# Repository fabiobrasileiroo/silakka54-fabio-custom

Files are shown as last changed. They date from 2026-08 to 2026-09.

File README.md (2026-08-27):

# Silakka54 — Pacote de Impressão "Fabio custom" (v3.0 "FB + Tux + linux + Kit 2-em-1")

Pasta autocontida com todo o histórico do projeto: dos arquivos originais (zip) até a
**versão final personalizada**, pronta para mandar imprimir.

> 🌐 **Site com visualizador 3D interativo (GitHub Pages):**
> **https://fabiobrasileiro.me/silakka54-fabio-custom/**
> (three.js via CDN + STLs servidos pelo jsDelivr; inclui guia de ergonomia)

## Referências visuais

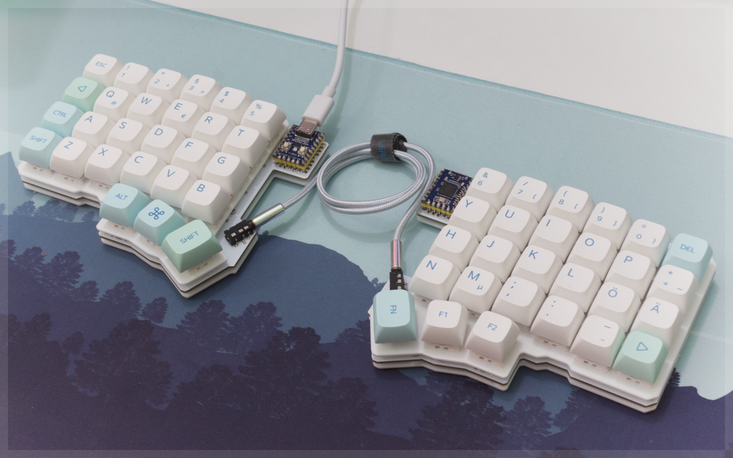
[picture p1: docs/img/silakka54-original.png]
Silakka54 original — teclado montado


Fotos de referência (de terceiros, para demonstrar como o teclado fica montado):

- **Original do autor** — [squalius-cephalus.github.io/silakka54](https://squalius-cephalus.github.io/silakka54/) (Patrick Faulkner)
- **Exemplo real montado** — [Reddit r/ErgoMechKeyboards](https://www.reddit.com/r/ErgoMechKeyboards/comments/1nzly97/my_first_split_silakka54_from_aliexp_w_3d_printed/) (`docs/img/silakka54-assembled.jpg`)

📸 A foto do meu teclado montado será adicionada quando chegar.

## Estrutura

```
silakka54-pacote-impressao/
├── README.md                    ← este arquivo (visão geral)
├── CHANGELOG.md                 ← histórico detalhado de todas as modificações
├── INSTRUCOES_IMPRESSAO.md      ← guia para a pessoa que vai imprimir (LEIA ANTES)
├── CHECKSUMS.sha256             ← hashes de integridade de todos os arquivos
├── pyproject.toml               ← dependências das ferramentas (uv / Python)
├── 00-original/
│   ├── case-keyboard/           ← arquivos ORIGINAIS do zip (intactos) + PDF de montagem
│   ├── carry-case/              ← arquivos ORIGINAIS do carry case (intactos) + PDF
│   └── tent-tilt-kit/           ← arquivos ORIGINAIS do kit ergonômico tent/tilt
├── 01-final/                    ← ⭐ VERSÃO FINAL PARA IMPRIMIR ⭐
│   ├── LH/                      ← baseplate "Foi o JavaScript..." (corrigida) + cover "FB + Tux + linux"
│   ├── RH/                      ← baseplate "Foi o Java..." (corrigida) + cover "FB + Tux + linux"
│   ├── comum/                   ← top frame (imprimir 1 direto + 1 espelhado)
│   ├── carry-tent-2em1/         ← Kit 2-em-1 Carry Case (67mm/standard) + plataforma Tent/Tilt
│   └── previews/                ← pré-visualizações das peças e plaquetas
├── ferramentas/                 ← scripts de regeneração (engrave_baseplate.py / engrave_cover.py)
└── 02-superseded/               ← versões anteriores arquivadas
```

## O que foi feito (resumo de 1 linha)

A case original foi customizada na **v3.0**: covers com plaqueta **"FB + silhueta Tux (Linux)"** e texto lateral **"linux"**, baseplates com **"Foi o JavaScript que me deu"** (LH) / **"Foi o Java que me deu"** (RH) gravadas na face inferior com **orientação 100% legível por baixo (sem espelhamento)**, e o **Kit 2-em-1 Carry Case + Tent** reunido e pronto para uso.

Detalhes completos (medidas, fontes, eixos de espelhamento, verificações): **CHANGELOG.md**.

## Para imprimir

1. Leia **INSTRUCOES_IMPRESSAO.md** (lista de peças, quantidades, orientação).
2. Use os arquivos de **`01-final/`** (incluindo `01-final/carry-tent-2em1/` para o kit 2-em-1).
3. Regra de ouro: **arquivos `*RH*` já vêm espelhados — nunca espelhar de novo**; o único
   espelhamento a fazer é **1 cópia do top frame** (lado direito).

## Para modificar depois

- Texto/fonte/tamanho/posição das gravações → dá para **regenerar por script**:
  `cd ferramentas && poetry run python engrave_cover.py` (dependências gerenciadas pelo
  Poetry via `pyproject.toml`; instale com `poetry install` na raiz).
- Carry case → pode ser adaptado depois (pendente, proposital).
- Tenting platform (ergonomia 10–15°) → **incluído**: `00-original/tent-tilt-kit/`
  (kit Tent & Tilt Ergonômico de Douglas Serrão, original sem modificação).

## Licenças / créditos

- **Silakka54** — Patrick Faulkner (GPL v2.0; remix permitido com atribuição).
- **Case "less screws" / screwless + carry case** — remix de Douglas Serrão.
- Fontes: Audiowide (OFL 1.1), JetBrains Mono (OFL 1.1), DejaVu Sans (tux.png —
  Wikimedia Commons, silhueta oficial do Linux).

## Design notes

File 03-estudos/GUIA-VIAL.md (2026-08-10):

# Guia de uso — Vial no Silakka54 (RP2040)

Como configurar o teclado **sem instalar nada**: via **Vial Web** (vial.rocks), com backup
e camadas. Baseado na documentação oficial do Vial e no firmware oficial do Silakka54
(repo Squalius-cephalus, v1.4 = Vial 0.7.5).

---

## 0. O que é o Silakka54 (seu teclado)

- Board **wired** com 2× RP2040 Zero (1 por metade), 54 teclas split colunar
  (6×4 + 3 thumb por metade), hotswap MX.
- Firmware oficial com **Vial embutido** = remapear ao vivo, sem recompilar nada.
- ⚠️ Existem clones **wireless** ("Silakka54 sem fio") que usam nice!nano/ZMK e **NÃO
  funcionam com Vial**. Se o seu é o *wired* com RP2040 (como o da AliExpress "QMK VIAL
  Programável RP2040 Zero"), está correto.

## 1. Do que você precisa

| Ferramenta | Onde | Quando |
|---|---|---|
| **Vial Web** (recomendado) | https://vial.rocks/ | Remapear, camadas, macros, backup |
| **Vial Desktop** (alternativa) | https://get.vial.today/download/ | Funciona offline; necessário no Linux p/ udev |
| **Manual oficial do Vial** (EN) | https://get.vial.today/manual/ | Dúvidas de funcionalidade |
| **Firmware oficial (UF2)** | https://github.com/Squalius-cephalus/silakka54/releases | Só se o teclado não for detectado |
| **Site do projeto** | https://squalius-cephalus.github.io/silakka54/ | Firmware + troubleshooting |

> 🌐 **Vial Web funciona melhor no Chrome/Edge** (usa WebHID). Firefox não suporta WebHID.

---

## 2. Primeira conexão (5 min)

1. **TRRS obrigatório**: conecte as 2 metades com cabo **TRRS (4 pinos)** — cabo TRS (3
   pinos) NÃO funciona. Connector de pré-montados costuma ser bem apertado: encaixe até o
   fim.
2. Conecte a **metade master** (a que tem USB) ao PC com cabo USB-C. Em teclados pré-montados
   da AliExpress, quase sempre é o lado que tem a porta + a ordem de flash define (LEFT/RIGHT).
3. Abra **https://vial.rocks/** → clique em **Connect** (ícone de teclado) → selecione o
   dispositivo "Silakka54".
4. **Teste todas as teclas**: aba **Key tester** (ou digite num editor) — confira se cada
   tecla responde. Se metade não responder, veja Troubleshooting (seção 7).
5. Se o layout mostrado no Vial não bater com o teclado físico, **atualize o firmware**
   (seção 6).

> 💡 If o precia: o firmware de fábrica dos pré-montados frequentemente tem **layout
> mínimo de 1 camada e keycaps trocadas** (ex.: pgup = Enter, del = Backspace). Não é
> defeito — é só remapear (seção 3).

---

## 3. Remapear teclas (o essencial)

1. No Vial Web, aba **Layout** (teclado desenhado em cima, paleta de teclas embaixo).
2. Clique na tecla física que quer mudar (ela fica destacada).
3. Clique na função nova na paleta (ou use a busca "Any key" para keycodes crus, ex. `KC_NO`).
4. **Já era** — a mudança é salva **na flash do teclado** imediatamente. Sobrevive a
   desligar, trocar de PC, tudo. Não precisa de "salvar" nem reflash.

Conceitos rápidos:
- **▽ (Transparent)**: "herda" da camada de baixo — usado para montar camadas.
- **MO(x)**: segura e ativa a camada x (mais usado).
- **LT(x, tecla)**: tap = tecla normal, hold = camada x (ex.: LT(1, Space)).
- **TG(x)**: liga/desliga a camada x (toggle).
- **OSL(x)**: camada x por UM toque (one-shot).
- **Layer Lock**: o firmware tem `LAYER_LOCK_ENABLE` — use tecla **QK_LLCK** para travar a
  camada atual (Caps Lock de camada).

## 4. Camadas — você tem 8!

O build Vial oficial do Silakka54 vem com **8 camadas** (`DYNAMIC_KEYMAP_LAYER_COUNT 8`),
muito mais que as 4 padrão do Vial. Sugestão de organiização:

| Camada | Função |
|---|---|
| 0 | Base (letras/números) |
| 1 | Símbolos e F-keys (via MO nas thumbs) |
| 2 | Navegação (setas, Home/End/PgUp/PgDn) |
| 3 | Mouse/Media (opcional) |

Dica de split de 54: coloque **Space / Enter / camadas nos thumb clusters** (3 thumbs por
metade) e tire a carga dos mindinhos. Exemplo de base:
- Esquerda: **Space** (thumb maior), **MO(1)** (thumb 2), **Backspace** (thumb 3)
- Direita: **Enter** (thumb maior), **MO(2)** (thumb 2), **Del** (thumb 3)

## 5. Macros, combos e tap-hold

- **Macros** (aba Macros): até 16 slots (M0–M15). Grave com **Record** ou monte ações na
  mão (tap/hold/delay). Atribua `M0` etc. a qualquer tecla. Ex.: M0 = "silakka54" +
  Enter; M1 = Ctrl+Shift+Esc.
- **Combos** (aba Combos): até 2–4 teclas juntas disparam UMA ação (ex.: **F+J = Enter**,
  **Esc = A+S**). Não ocupa slot de tecla — ótimo em split pequeno.
- **Tap-hold / home-row mods** (aba QMK Settings): ajuste `Tapping Term` (ex.: 180–220 ms).
  Se uma tecla "segurar vira shift" está disparando shift sem querer, aumente o termo.

## 6. Atualizar firmware (só se precisar)

**Quando**: teclado não aparece no Vial, ou quer a versão mais recente (v1.4, Vial 0.7.5,
com suporte a LEDs de camada).

1. **Backup primeiro**: Vial → `File` → `Save current layout` → salve seu `.vil` (o reflash
   **apaga o layout**). Desde o Vial 0.7.5 o **web app** (vial.rocks) também salva/abre
   `.vil` — Chrome/Edge: menu do layout (ou Ctrl+S / Ctrl+O). O firmware v1.4 do Silakka54
   já vem com Vial 0.7.5.
2. Baixe o **UF2** em https://github.com/Squalius-cephalus/silakka54/releases:
   - `silakka54_vial_LEFT.uf2` → metade esquerda
   - `silakka54_vial_RIGHT.uf2` → metade direita
   - (existe versão `NO_USBDETECT` se a normal não funcionar)
3. **Mode bootloader** de 2 jeitos:
   - Sem firmware: segure **BOOT** no RP2040 Zero e conecte ao USB.
   - Com firmware: **duplo clique no botão reset** → aparece drive USB.
4. **Arraste o `.uf2`** para o drive (drag-and-drop). A placa reinicia sozinha.
5. Repita na outra metade com o arquivo da outra metade (ou mesmo LEFT nas duas para
   forçar USB na esquerda; RIGHT nas duas para USB na direita).
6. Reabra o Vial e **carregue o `.vil`** de volta (`File` → `Load saved layout`).

> Se o Vial Web não for detectar o teclado no Linux com o app desktop: siga
> https://get.vial.today/manual/linux-udev.html (regra udev fornecida).

## 7. Troubleshooting rápido

| Sintoma | Causa provável | Solução |
|---|---|---|
| Metade direita morta | Cabo TRRS solto/apertado, ou **TRS** (3 pinos) | Encaixe com força; troque por TRRS |
| Teclas "trocadas" (pgup=Enter etc.) | Keycaps de fábrica mal rotuladas | Remapeie no Vial (ou troque keycaps) |
| Teclado some ao reiniciar o PC | Firmware antigo (issue de boot) | Atualizar para v1.4 |
| Vial não conecta | Versão wireless (ZMK) ou firmware faltando | Verificar modelo; reflash UF2 |
| Texto/tecla errada ao digitar | Layout do SO ≠ layout do teclado | Ajuste no sistema (ABNT2/US Intl) e remapeie |
| Algumas teclas sem resposta | Pino de switch torto / socket | Tira e recoloca o switch (pinos retos) |
| Vial Web mostra teclado "bloqueado" | Proteção de segurança do Vial Web | Digite o unlock combo **Esc + 1** (tecla de esc + tecla 1 juntas) para desbloquear |

**Referências**: manual oficial Vial (https://get.vial.today/manual/) · firmware oficial
Silakka54 (https://squalius-cephalus.github.io/silakka54/firmware.html) · repo
(https://github.com/Squalius-cephalus/silakka54).

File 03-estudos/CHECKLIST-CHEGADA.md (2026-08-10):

# Checklist "Dia 1" — quando o Silakka54 chegar

Ordem cronológica para montar, testar e configurar. Imprima ou abra no celular.

---

## □ Antes de abrir (planejar)

- [ ] Reserve mesa limpa + luz; tenha em mãos:
  - cabo **USB-C** (pré-montados da AliExpress às vezes **NÃO incluem**)
  - cabo **TRRS** (4 pinos) — se não veio, compre; TRS não funciona
  - chave de fenda pequena (não deve precisar para hotswap)
- [ ] Abra https://vial.rocks/ no **Chrome/Edge** para testar (guardar no favoritos)
- [ ] Tenha em mente: os dois zips/case impressa em `silakka54-pacote-impressao/`

## □ Unboxing físico

- [ ] Confira itens: 2 metades, switches (se kit), keycaps, cabos
- [ ] Se for kit (montar): coloque os **switches** nos sockets hotswap — pinos retos,
      força para baixo até o "click". Não force torto!
- [ ] Coloque as **keycaps** (⚠️ as de fábrica podem vir trocadas: pgup=Enter, del=Backspace —
      normal, remapear depois)
- [ ] Se usar a case impressa: monte baseplate + top frame → encaixe o PCB → covers chevron

## □ Conexão e primeiro teste

- [ ] Conecte as metades com o **TRRS** (ate o fim — conector de pré-montado é apertado)
- [ ] USB-C na **metade master** (a que tem o conector) → PC
- [ ] Abra https://vial.rocks/ → **Connect** → deve aparecer "Silakka54"
- [ ] **Key tester**: teste TODAS as 54 teclas (com o software "Key tester" ou num editor
      de texto) — as duas metades respondem?
- [ ] NÃO apareceu? → atualizar firmware (ver GUIA-VIAL.md seção 6: BOOT + uf2)

## □ Configuração no Vial (30–60 min)

- [ ] Mapear base: corrigir keycaps trocadas; colocar **camadas nas thumbs** (ex.:
      MO(1) thumb esquerda, MO(2) thumb direita, Space/Enter nas thumbs grandes)
- [ ] Camada 1: **setas + Home/End/PgUp/PgDn** + símbolos que usa muito
- [ ] Camada 2: **F1–F12** + atalhos (Ctrl+Shift+Esc etc.) — você tem **8 camadas**!
- [ ] (Opcional) Combos: Esc = A+S, Enter = F+J
- [ ] Ajustar **Tapping Term** (QMK Settings) se usar home-row mods
- [ ] **Backup**: File → Save current layout → `silakka54-layout-dia1.vil`
      (guarde uma cópia dentro de `silakka54-pacote-impressao/03-estudos/backups/`)

## □ Setup ergonômico na mesa (ver REPORT-ERGONOMIA.md)

- [ ] Metades na **largura dos ombros**, anguladas para dentro (punhos retos)
- [ ] Teclado **abaixo da altura do cotovelo** (cotovelo ~90°, antebraços apoiados)
- [ ] Slope **0° a −4°** — NÃO use pés traseiros se a case tiver (frente levemente alta)
- [ ] **Tenting** 10–15°: adicionar (kit Tent & Tilt / cunhas / parafusos assimétricos)
- [ ] Mãos **flutuando** — nada de encostar o pulso na mesa durante digitação
- [ ] Monitor no topo na altura dos olhos, ~50–70 cm

## □ Semana 1 (adaptação)

- [ ] Aceite a queda de velocidade: 2–4 semanas para voltar ao ritmo
- [ ] Use keybr.com / monkeytype com o layout para treinar memória muscular
- [ ] Micro-pausa a cada 20–30 min + alongamento de punhos
- [ ] Ajuste camadas conforme a dor/desconforto de alcance aparecer
- [ ] Salve novo `.vil` a cada mudança grande (backup!)

## □ Referências rápidas

| O quê | Onde |
|---|---|
| Guia Vial completo | `03-estudos/GUIA-VIAL.md` |
| Ergonomia científica | `03-estudos/REPORT-ERGONOMIA.md` |
| Guia visual animado | `03-estudos/GUIA-ERGONOMIA-VISUAL.html` |
| Firmware/UF2 | https://github.com/Squalius-cephalus/silakka54/releases |
| Manual Vial | https://get.vial.today/manual/ |

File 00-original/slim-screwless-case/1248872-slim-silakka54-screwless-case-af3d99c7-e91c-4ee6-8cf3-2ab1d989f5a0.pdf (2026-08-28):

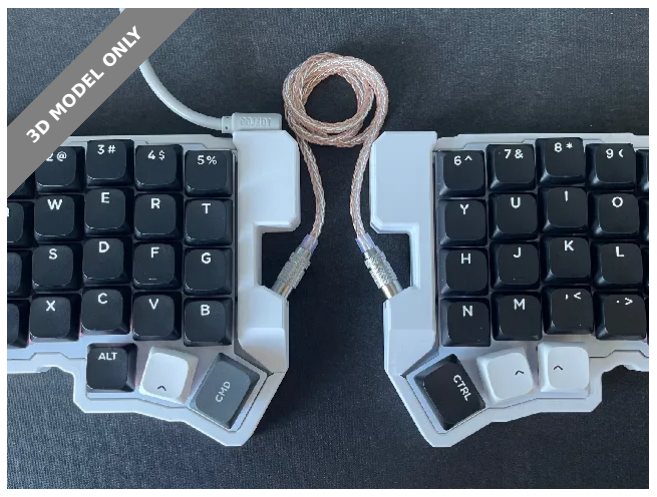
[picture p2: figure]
3D MODEL ONLY

## Summary

Remix of the original Silakka54 case to be slimmer and screwless using friction fitting only

Gadgets (https://printables.com/model?categoryId=21) > Computers (https://printables.com/model?categoryId=27)

Tags: | case | keyboard | mechanicalkeyboard | ergonomic | ergo
silakka54

This remix of the original Silakka54 case has the following differences:

case bottom is now solid
case top has been integrated into the case bottom
case sides walls has been reduced by 50%
case walls are now shorter and matches the height of the top plate removed the screw holes and replaced with studs for the MCU cover PCB friction fits into the case
MCU cover friction fits into case studs
inner frame to support the pcb and top plate for outer edges

You may want to experiment with printing the mcu covers at different angles to get the optimum print quality.

I used the ironing function with ironing speed of 65mm/s and ironing flow rate of 22% with spacing of 0.15 to get a nice top surface finish.

J (https://printables.com/@Johnny5iv_3103862) Johnny5iv (https://printables.com/@Johnny5iv_3103862)

## Slim Silakka54 screwless case

VIEW IN BROWSER (https://printables.com/model/1248872-slim-silakka54-screwless-case)

updated 25. 6. 2025 | published 25. 6. 2025

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
## Model files

Note: This model currently only fits the AliExpress pcb plates up to v1.2. The newer v1.3 pcb plates are slightly larger around the MCU controller.

Will be making an updated model to work with v1.3 in future.

## This remix is based on

Silakka54 Case (https://printables.com/model/1167880-silakka54-case)
by Squalius (https://printables.com/@Squalius_483570)
- Contains both the case and mcu cover in one file
- Contains both the case and mcu cover in one file

silakka54_mcu_right.stl

silakka54_top_bottom_right.stl

silakka54_top_bottom_mcu_left.stl

silakka54_mcu_left.stl

silakka54_top_bottom_mcu_right.stl

silakka54_top_bottom_left.stl

- inner frame to go in between the pcb and the top plate

## License

This work is licensed under a GNU

General Public License v2.0 (http://www.gnu.org/licenses/old-licenses/gpl-2.0.html)

✖ | Sharing without ATTRIBUTION
✔ | Remix Culture allowed
✔ | Commercial Use
✔ | Meets Open Definition
ℹ | Share under the same license

silakka54_inner_frame.stl

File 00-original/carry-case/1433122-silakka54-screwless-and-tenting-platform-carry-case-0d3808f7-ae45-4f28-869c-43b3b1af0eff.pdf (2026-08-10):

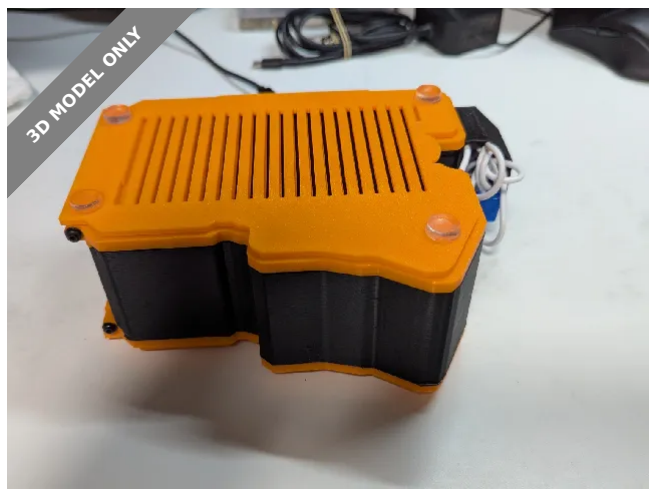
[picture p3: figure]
3D MODEL ONLY

## Summary

Simple carry case to hold a silakka54 that's using the screwless case and the tenting platform.

Gadgets (https://printables.com/model?categoryId=21) > Computers (https://printables.com/model?categoryId=27)

Tags: | keyboard | ergonomic | splitkeyboard | ergonomickeyboard
silakka54 | silakka

Update 2026-03-18

Added a 67mm high case that can accommodate taller keycaps, such as these:

This is built around the excellent screwless case (https://www.printables.com/model/1248872-slim-silakka54-screwless-case) and tenting platform, (https://www.printables.com/model/1312117-silakka54-tent-tilt-ergonomic-kit-for-slim-screwle) and provides a carry case with a slot to hold the cable.

Use a rubber band to hold the case closed, since it's set to be a bit loose when assembled (to make it easier to remove the keyboard).

It also works without the tenting platform as in the picture.

Snazzer (https://printables.com/@snazzer_2962879)

## Silakka54 Screwless and Tenting Platform carry case

VIEW IN BROWSER (https://printables.com/model/1433122-silakka54-screwless-and-tenting-platform-carry-cas)

updated 18. 3. 2026 | published 18. 3. 2026

•

## Model files

I'm using low profile keycaps, but i did a height test with some cherry keys and it seems to work fine. Let me know if there are issues.

Print at 15% infill, 2 walls. I printed mine at 0.32mm height for speed, but it should work just fine with the usual 0.2mm height.

Print with supports as pictured, with a blocker to disable support for the cord holder since it will be mostly fine with bridging. You can also allow support there if you want cleaner internal ceiling in that section.

## This remix is based on

Slim Silakka54 screwless case (https://printables.com/model/1248872-slim-silakka54-screwless-case) by Johnny5iv (https://printables.com/@Johnny5iv_3103862)

Silakka54 Tent & Tilt Ergonomic Kit (for Slim Screwless Case) (https://printables.com/model/1312117-silakka54-tent-tilt-ergonomic-kit-for-slim-screwle)
by Douglas Serrão (https://printables.com/@DouglasSerra_2961641)

## License

This work is licensed under a GNU (http://www.gnu.org/licenses/old-licenses/gpl-2.0.html)

silakka54-case.stl

silakka-case-67mm.stl

General Public License v2.0 (http://www.gnu.org/licenses/old-licenses/gpl-2.0.html)

✖ | Sharing without ATTRIBUTION
✔ | Remix Culture allowed
✔ | Commercial Use
✔ | Meets Open Definition
ℹ | Share under the same license

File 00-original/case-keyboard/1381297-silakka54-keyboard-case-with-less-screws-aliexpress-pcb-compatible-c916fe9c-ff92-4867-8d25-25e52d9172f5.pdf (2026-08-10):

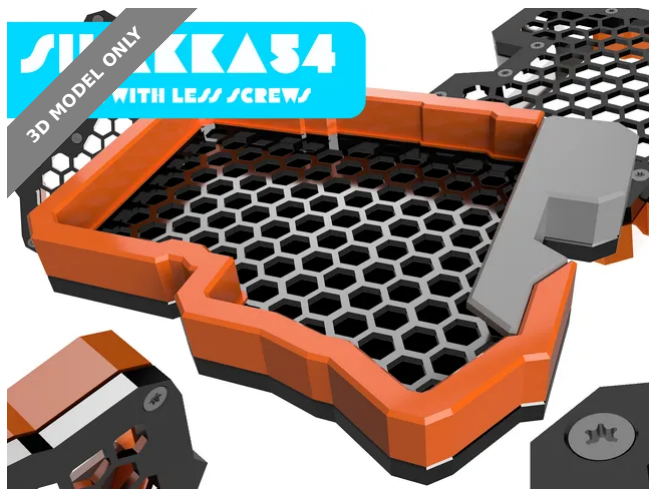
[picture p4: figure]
3D MODEL ONLY

## Summary

Keyboard case for a Silakka54 designed for Polyfix/Plastite Screws Fits AliExpress PCB's, original credit to Squalius

Gadgets (https://printables.com/model?categoryId=21) > Computers (https://printables.com/model?categoryId=27)

Tags: | case | screws | patrick | mechanical | mech | screw
custom | usb | keyboard | split | ergonomic | compatible
ergo | splitkeyboard | splitkeyboardcase | silakka54 | faulkner
ergosplit | polyfix | silakka

Simple changes to the standard case - Parts are for LH, please mirror in printing to make RH parts.
Now compatible with AliExpress PCB's too!
Heat press inserts are removed and replaced with holes for a countersunk Polyfix or self tapping screw between 2.5x10 and 3x16 in size - I use these (https://www.accu.co.uk/plastite-30-hexalobular-torx-countersunk-screws/371154-SHK30-3-12-A2) but any similar size self tapping screw should work.
You will need 11 screws per side, 22 total but you might be able to get away with as little as 5 per side depending on use.

Patrick Faulkner (https://printables.com/@Faulkner)

## Silakka54 Keyboard Case -With Less Screws* AliExpress PCB Compatible

VIEW IN BROWSER (https://printables.com/model/1381297-silakka54-keyboard-case-with-less-screws-aliexpres)

updated 20. 8. 2025 | published 20. 8. 2025

## Model files

Some small features have been removed or simplified in the hex grid for the keyboard base to make a simpler print.
Parts required to make each side of the case are 1x base and 1x Top frame, then you have a choice of Covers for the RP2040, from “no cover top frame” which continues the case edge but leaves to top open, all the way to "full MCU cover" with two options in-between.
MCU Cover Heights are Increased from standard, The PCB's I've tested with have collisions with the standard covers. I'll post a more drastic update with some bigger changes to fix this soon.
*Less screws is really less components - Its the same amount of holes at the moment.

## This remix is based on

Silakka54 Case (https://printables.com/model/1167880-silakka54-case)
by Squalius (https://printables.com/@Squalius_483570)
- Now Compatible with AliExpress PCB's!
- Now Compatible with AliExpress PCB's!
- Fancier cover raised height for MCU clearance silakka54-baseplate-screwunderneath.stl

silakka54-top-frame-screwunderneath.stl

no-cover-top-frame.stl

full-mcu-cover-chevrons.stl

- raised height for MCU clearance
- raised height for MCU clearance
- raised height for MCU clearance

## License

This work is licensed under a GNU

General Public License v2.0 (http://www.gnu.org/licenses/old-licenses/gpl-2.0.html)

✖ | Sharing without ATTRIBUTION
✔ | Remix Culture allowed
✔ | Commercial Use
✔ | Meets Open Definition
ℹ | Share under the same license

50pct-mcu-cover.stl

75pct-mcu-cover.stl

full-mcu-cover.stl

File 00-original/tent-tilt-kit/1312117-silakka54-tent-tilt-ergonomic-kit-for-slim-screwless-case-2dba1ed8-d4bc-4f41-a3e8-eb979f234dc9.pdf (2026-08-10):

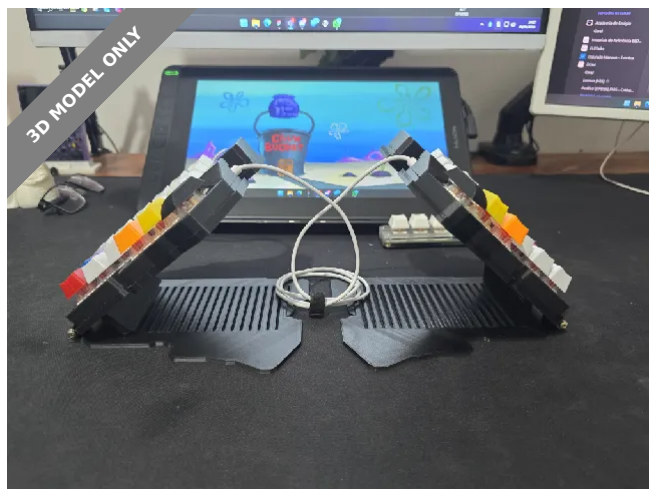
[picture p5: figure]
3D MODEL ONLY

## Summary

Silakka54 Tent & Tilt Ergonomic Kit (for Slim Screwless Case)

Gadgets (https://printables.com/model?categoryId=21) > Other Gadgets (https://printables.com/model?categoryId=43)

Tags: | keyboard | ergonomic

Kit de mala e tenda para Silakka54

Este kit é compatível exclusivamente com o estojo sem parafusos Slim Silakka54:
https://www.printables.com/model/1248872-slim-silakka54-screwless-case

Ele fornece um sistema de suporte ajustável para elevação ergonômica do teclado mecânico Silakka54, usando um mecanismo de tenda levantado ao centro para melhorar a postura e o conforto da digitação.

Importante: Este kit só deve ser impresso se você já tiver impresso o estojo sem parafusos Slim Silakka54. Todas as peças neste projeto foram projetadas especificamente como complementos para esse gabinete e não se encaixam em outros modelos.

Douglas Serrão (https://printables.com/@DouglasSerra_2961641)

## Silakka54 Tent & Tilt Ergonomic Kit (for Slim Screwless Case)

VIEW IN BROWSER (https://printables.com/model/1312117-silakka54-tent-tilt-ergonomic-kit-for-slim-screwle)

updated 29. 5. 2025 | published 29. 5. 2025

## Model files

## Other files

## This remix is based on

Slim Silakka54 screwless case (https://printables.com/model/1248872-slim-silakka54-screwless-case) by Johnny5iv (https://printables.com/@Johnny5iv_3103862)

silakka54_left_side_shell.stl

silakka54_left_base_support.stl

silakka54_right_base_support.stl

silakka54_right_side_shell.stl

silakka54_tilt_wedge_xdeg.stl

instrucoes-instructions.txt

## License

This work is licensed under a GNU

General Public License v2.0 (http://www.gnu.org/licenses/old-licenses/gpl-2.0.html)

✖ | Sharing without ATTRIBUTION
✔ | Remix Culture allowed
✔ | Commercial Use
✔ | Meets Open Definition
ℹ | Share under the same license

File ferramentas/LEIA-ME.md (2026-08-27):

# ferramentas/ — ferramentas de regeneração

Ferramentas que **regeneram** os arquivos finalizados (`01-final/`). Use
qualquer mudança futura nas gravações ou previews sem mexer à mão nos STLs.

Dependências gerenciadas via `uv` / Python (`./ferramentas/uv run` ou `poetry run`):
`trimesh`, `numpy`, `shapely`, `matplotlib`, `pillow`, `manifold3d`.

---

## engrave_baseplate.py — gravações nas baseplates (face inferior corrigida)

Gera as baseplates com as frases gravadas na face inferior, com espelhamento 2D horizontal corrigido para visualização natural e legível por baixo do teclado:

```bash
./ferramentas/uv run python3 ferramentas/engrave_baseplate.py --side BOTH
```

---

## engrave_cover.py — gravações nos covers (FB + Tux + linux)

Reproduz o design atual da v3.0:

```bash
./ferramentas/uv run python3 ferramentas/engrave_cover.py --side BOTH --plaque-text FB --tux --side-text linux
```

Saída: `silakka54-chevron-cover-<LETRA>[-<extra>][-<lateral>]-<LH|RH>.stl`
em `--out-dir` (default `out/`). Depois de gerar, copie para `01-final/`.

### Flags mais usados

| Flag | Default | O que faz |
|---|---|---|
| `--side-text 'X'` | `linux` | texto lateral (passe `''` para remover) |
| `--plaque-bottom 'vim'` | — | texto secundário empilhado na plaqueta |
| `--plaque-cap 5.0` | `5.0` | altura da letra da plaqueta (mm) |
| `--side-cap 3.5` | `2.6` | altura do texto lateral (limite ~3 mm) |
| `--depth 0.55` | `0.55` | profundidade da gravação (mm) |
| `--side-x auto` | `auto` | X do centro do texto lateral (ou número) |
| `--side-y -80` | `-80` | Y do centro do texto lateral |
| `--side-rot -90` | `-90` | rotação do texto lateral (graus) |
| `--plaque-font` / `--side-font` | audiowide / jetbrains-mono-bold | fontes em `fonts/` |
| `--base <stl>` | `00-original/.../full-mcu-cover-chevrons.stl` | mesh base |
| `--verify` | off | imprime mapas ASCII da região gravada |
| `--quiet` | off | silencia logs |

### Regra crítica

**Nunca espelhe um `*RH*`.** O script já gera o lado direito no sentido
correto; espelhar de novo inverte as gravações.

---

## make_previews.py — previews PNG das peças (site)

Renderiza um STL em PNG para os cards do site (fundo `#161b22`, cor por
peça, perspectiva 3D fixa):

```bash
poetry run python make_previews.py <stl> <out.png> [--color RRGGBB] [--elev 25] [--azim -60]
```

Exemplo (cores iguais às do viewer 3D do site):

```bash
poetry run python make_previews.py ../01-final/LH/silakka54-chevron-cover-F-linux-LH.stl \
  ../01-final/previews/preview-F-linux-LH.png --color f2a33c
```

Saída: PNG quadrado 1440×1440 em `01-final/previews/`. Manter o mesmo
padrão de nome `preview-<id>.png` — o site referencia por esse caminho.

---

## Fluxo sugerido ao alterar uma gravação

1. `engrave_cover.py` com os novos parâmetros → confira com `--verify` → copie p/ `01-final/`.
2. `make_previews.py` → atualize o preview da peça em `01-final/previews/`.
3. Commit + push → o site (via jsDelivr CDN) e o README refletem automaticamente.

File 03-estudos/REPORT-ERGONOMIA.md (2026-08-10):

# Relatório de Ergonomia — Como usar o Silakka54 (com base em estudos científicos)

Este relatório traduz a literatura científica em **instruções práticas** de como sentar,
posicionar o teclado e usar as mãos. Vale para o Silakka54 (54 teclas, split colunar) e para
qualquer estação de trabalho.

> ⚠️ Regra de ouro da ergonomia: **é o conjunto que importa** — cadeira + mesa + teclado +
> monitor + pausas. O teclado perfeito sobre uma mesa errada não resolve nada
> (The Heаrthful Home, "Keyboard Ergonomics Explained", 2026).

---

## 1. Postura completa (checklist visual)

Arranjo ideal da estação, de baixo para cima:

| Parte do corpo | Posição ideal | Fonte |
|---|---|---|
| **Pés** | Firmes no chão (ou descanso de pés) | Cornell CUergo |
| **Joelhos/quadril** | ~90° de flexão | Portal São Francisco / diretrizes gerais |
| **Coluna** | Lombar apoiada no encosto da cadeira, levemente reclinada | Cornell CUergo — "slightly reclined sitting position" |
| **Cotovelos** | **90°–100°**, próximos ao tronco, antebraços ~paralelos ao chão | ProtoArc 2026; Mork & Westgaard 2007 |
| **Antebraços** | **Apoiados** (mesa ou apoio de braço) — reduz carga de ombro/pescoço | Mork & Westgaard 2007 (doi 10.1007/s00421-007-0518-4) |
| **Pulsos** | **Neutros e retos** (extensão <15°), mãos **flutuando** sobre as teclas | Rempel; Cornell CUergo |
| **Ombros** | Relaxados, não encolhidos nem abduzidos | WorksmartHub |
| **Monitor** | Topo da tela na altura dos olhos, ~50–70 cm de distância, sem torcer o pescoço | Portal São Francisco; diretrizes gerais |

**O ponto mais importante para quem compra um split**: o teclado **abaixo** da altura do
cotovelo, com **slope negativo** (frente do teclado mais alta que o fundo). É a
"Negative slope keyboard support" da Cornell — a postura que minimiza carga muscular
estática.

---

## 2. O Silakka54 resolve o quê? (e o que falta resolver)

| Problema do teclado tradicional | O que o Silakka54 faz | Evidência |
|---|---|---|
| **Desvio ulnar** (punho dobrado para fora) | ❌ Resolvido — split colunar alinha mão/antebraço | Marklin & Simoneau 2001: split reduz desvio ulnar de ~12° para **<5°** (PubMed 11276185) |
| **Pronação do antebraço** (palma virada para baixo) | ⚠️ Parcial — precisa de **tenting 10°–15°** | Chen et al. 2009 (NIOSH); Rempel et al. 2007 (gable 14° ótimo) |
| **Extensão de punho** (dedos para cima) | ⚠️ Parcial — precisa de **slope 0° a −4°** | Chen et al. 2009: slopes 0° a −4° = menor extensão e menor pressão no túnel do carpo |
| **Ombros encolhidos / braços juntos** | ✅ Resolvido — metades na **largura dos ombros** | Dygma: split abre o peito e solta os ombros |
| **Alcance lateral** (F-keys, setas, mouse longe) | ✅ Resolvido — tudo chega via **camadas** (Vial) | Protocolo padrão de teclados pequenos |

**Tradução**: o split já te dá 60% do caminho. Os outros 40% vêm de **tenting (10°–15°) +
altura do cotovelo + slope neutro/negativo + pausas**.

---

## 3. Como posicionar o teclado na mesa (visão de cima)

Recomendação direta (Dygma "How to position your split keyboard", 2023):

1. **Comece junto**: metades quase juntas, levemente anguladas para dentro — as mãos
   alinhadas com os antebraços, punho SEM dobra para fora. Esse é o "ângulo zero".
2. **Abra aos poucos**: aumente a separação das metades até ficar na **largura dos ombros**.
   O peito abre, as costas endireitam sem esforço.
3. **Mouse no espaço central** (entre as metades ou ao lado), no mesmo plano do teclado,
   perto — sem esticar o braço.
4. **Regra de posicionamento**: cada metade fica **na frente do ombro correspondente**,
   não no centro do corpo. Se usar só uma metade, posicione o mouse "no lugar da metade
   faltante".

---

## 4. Tenting e slope — os ângulos "ideais"

### Tenting (rotação lateral das metades)

- **Por que**: reduz a **pronação** (rotação interna do antebraço que força a palma para
  baixo).
- **Quanto**: **10°–15°** é a faixa consensual. Rempel et al. 2007 (100 digitadores, 6
  teclados): combinação que deu postura mais neutra = **gable/abertura ~14°, slope 0°**.
  Acima de 20°–30° começa a sobrecarregar ombro/pescoço.
- **No Silakka54**: a case imprime plana (**0°**). Opções para tentear:
  - imprimir o kit **"Tent & Tilt Ergonomic Kit"** (Douglas Serrão — remix do *Slim
    Silakka54 screwless case* de Johnny5iv) — **já incluído** neste pacote em
    `00-original/tent-tilt-kit/` (side shells + base supports + tilt wedge, conforme PDF);
  - ou usar parafusos/pés de borracha assimétricos (~12° ≈ uma forma barata de tenting);
  - ou imprimir cunhas de tenting sob medida (podemos modelar para a sua baseplate).

### Slope (inclinação frente→trás)

- **Por que**: teclado com a traseira mais alta (slope positivo) força **extensão do
  punho** — o desvio mais associado ao túnel do carpo.
- **Quanto**: **0° a −4°** (frente levemente mais alta que o fundo, ou mesa plana) —
  Chen et al. 2009 (NIOSH, estudo com teclado split "gabled"): slopes de 0° a −4° deram
  a menor extensão de punho, menor pronação e cotovelo mais baixo.
- **Na prática**: **NÃO use os pés traseiros de apoio** (aumentam o slope positivo).
  Prefira o teclado deitado ou com inclinação negativa (frente levantada).

---

## 5. Mãos: apoiar ou não apoiar? (a resposta científica)

**Contraintuitivo, mas claro na literatura: apoiar o PULSO é ruim.**

- O protocolo dos estudos de pressão no túnel do carpo (Rempel et al. 2008; CDC 2008)
  **proibia** voluntários de apoiar as mãos/pulsos em qualquer superfície durante a
  digitação — justamente porque a **pressão de contato na palma/pulso AUMENTA a pressão
  no túnel do carpo**.
- Apoio de **palma** (parte carnuda da mão, não o pulso) na **mesma altura das teclas** é
  aceitável — e útil como **apoio para pausas**, não durante a digitação
  (2021 J. Hand Therapy review; ProtoArc 2026).
- O que a literatura realmente apoia: **antebraço apoiado** na mesa/apoio de braço e
  **mãos flutuando** (hover) sobre as teclas — isso reduz carga de ombro
  (Mork & Westgaard 2007) sem aumentar pressão no punho.
- **Palm rest impresso (TPU)**: se quiser, pode imprimir um palm rest na altura das
  teclas para pausas — mas não encoste o punho nele durante a digitação.

---

## 6. Treino e adaptação (realista)

- **Curva de aprendizado**: 2 a 4 semanas para voltar à velocidade anterior
  (ProtoArc 2026). Grave e aceite a queda inicial de velocidade.
- **Regra de dedos estrita**: o split colunar tem colunas por dedo — não "roube" tecla da
  outra metade. A precisão volta antes da velocidade.
- **Thumb clusters**: os 3 polegar por metade são ouro — mapeie neles as teclas mais
  usadas (Space/Layer/Enter) para tirar carga dos mindinhos.
- **Micro-pausas**: a cada 20–30 min, solte as mãos, estique dedos e reset a postura.
  Movimento > pose perfeita.
- **Digitação guiada**: use keybr.com/monkeytype com layout do teclado para construir
  memória muscular.

---

## 7. Vídeos recomendados (YouTube)

| Vídeo | Canal | Por que assistir |
|---|---|---|
| [How to Set Up Your First Split Keyboard for Ergonomics](https://www.youtube.com/watch?v=QkJCyvwq5Ck) | — (2024) | Posicionamento das metades, largura do split, ângulo e mouse — exatamente o passo a passo da seção 3 |
| [SPLIT KEYBOARDS: How to Use Them, Why They're Great](https://www.youtube.com/watch?v=e1dUeoL_t00) | — | Visão geral em PT: funcionamento do teclado dividido, experiência prática |
| [Are Split Keyboards Better For Ergonomics?](https://www.youtube.com/watch?v=1C2bJkzIaPE) | Ben Vallack | Referência da comunidade ergo — análise honesta do ângulo de pulso em teclados fixos vs split |
| Canal [Ben Vallack](https://www.youtube.com/@BenVallack) | Ben Vallack | O youtuber de referência de teclados ergonômicos: camadas, thumb clusters, layouts |
| Canal [Dygma Lab](https://www.youtube.com/c/DygmaLab) | Dygma | Guias visuais de posicionamento e tenting (vídeo embutido no post "How to position your split keyboard") |

> Dica de busca: no YouTube, pesquise **"split keyboard ergonomics setup"** ou
> **"teclado split postura"** — os vídeos da Dygma e do Ben Vallack são os mais citados
> pela comunidade r/ErgoMechKeyboards.

---

## 8. Fontes citadas (para estudar a fundo)

1. **Chen et al. 2009** — *Effects of split gabled keyboard geometry on upper body postures and comfort* (NIOSH) — https://stacks.cdc.gov/view/cdc/189560
2. **Rempel et al. 2007** — *A randomized controlled trial evaluating the effects of six workstations on mouse forearm posture, carpal tunnel pressure...* / estudo com 100 digitadores (gable 14°, slope 0°) — via Xah Lee survey: http://xahlee.info/kbd/ergonomic_keyboard_science.html
3. **Rempel et al. 2008 (HF review)** — *The Split Keyboard: An Ergonomics Success Story* — http://xahlee.info/kbd/i2/split_keyboard__david_Rempel_2008_HF.pdf
4. **CDC 2008** — estudo de pressão no túnel do carpo (contato palmar) — https://stacks.cdc.gov/view/cdc/189560/cdc_189560_DS1.pdf
5. **Marklin & Simoneau 2001** — *Effect of setup configurations of split computer keyboards on wrist ulnar deviation* — https://pubmed.ncbi.nlm.nih.gov/11276185 (90 digitadores; desvio ulnar 12° → <5°)
6. **Cornell CUergo** — *Neutral Posture Typing* (slope negativo, cotovelo ~90°) — https://ergo.human.cornell.edu/AHTutorials/typingposture.html
7. **Mork & Westgaard 2007** — antebraços apoiados reduzem carga de ombro — doi 10.1007/s00421-007-0518-4
8. **Dygma 2023** — *How to position your split keyboard* — https://dygma.com/blogs/ergonomics/how-to-position-your-split-keyboard
9. **The Hearthful Home 2026** — *Keyboard Ergonomics Explained: Angle, Split, and Wrist Position* — https://thehearthfulhome.com/keyboard-ergonomics-angle-split-wrist-position/
10. **ProtoArc 2026** — *Split Keyboard Touch Typing Tips* (tenting 5–15°, cotovelo 90–100°, split na largura dos ombros) — https://www.protoarc.com/blogs/news/split-keyboard-typing-tips-ergonomics

---

*Guia gerado em 2026-08-09. Consulte também `GUIA-ERGONOMIA-VISUAL.html` (guia animado) e
`GUIA-VIAL.md` (configuração do teclado).*

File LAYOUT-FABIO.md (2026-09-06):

# Layout de Alta Performance: Silakka54 para Vim, DWM e Português (US-Intl)

Este layout foi desenhado sob medida para o **Silakka54 (54 teclas)**, otimizando o fluxo de trabalho com **DWM**, **Vim/LazyVim**, **VSCode** e digitação natural em **Português (Brasil)** usando o padrão `setxkbmap -layout us -variant intl`.

---

## 🎯 Princípios Ergonômicos do Design

1. **Acentuação em Português sem atrito**:
   - `KC_QUOT` (`'` e `"`) mantido na Home Row direita (ao lado do `;`), preservando a memória muscular de teclados tradicionais (ex: AULA F75) para digitação de `'` + `c` = `ç`, `'` + `a` = `á`, etc.
   - `KC_GRAVE` (`` ` `` e `~`) posicionado no canto superior esquerdo para acesso imediato a `~` + `a` = `ã` e crases sem malabarismos.
   - `KC_RALT` (AltGr) no polegar direito para atalhos diretos (`AltGr + ,` = `ç`, `AltGr + /` = `°`).

2. **DWM Seamless (Mod4 / Super)**:
   - `Super` (`KC_LGUI`) posicionado estrategicamente no **polegar esquerdo**, tornando atalhos como `Super + Enter` (abrir terminal `st`), `Super + d` (dmenu), `Super + j/k` (foco de janelas) e `Super + 1..4` (workspaces) totalmente confortáveis e sem esticar a mão.
   - A linha numérica superior dedicada física (`1 2 3 4 5 6 7 8 9 0`) permite alternar tags no DWM instantaneamente.

3. **Vim & VSCode Navigation**:
   - **CapsLock Dual-Role (`LCTL_T(KC_ESC)`)**: Toque rápido emite `ESC` (ideal para sair do modo Insert no Vim). Segurar funciona como `CTRL` padrão para atalhos de terminal (`Ctrl+C`, `Ctrl+Z`, `Ctrl+R`).
   - **Camada NAV (Layer 1)**: Ao segurar o polegar esquerdo, a mão direita transforma-se nas setas do Vim (`H`, `J`, `K`, `L`), com `Home` (`U`), `End` (`P`), `Page Up` (`I`) e `Page Down` (`O`).

4. **Símbolos de Programação (Layer 2)**:
   - Parênteses `( )`, chaves `{ }`, colchetes `[ ]` e sinais de menor/maior `< >` dispostos lado a lado na mão esquerda, sem necessidade de esticar o mindinho para a linha de números com Shift.

---

## 🗺️ Mapa das Camadas

### Layer 0: BASE (QWERTY US-Intl)
```text
[L-Half]
Row 0:  ` / ~    1      2      3      4      5
Row 1:  TAB      Q      W      E      R      T
Row 2:  ESC/CTL  A      S      D      F      G
Row 3:  SHIFT    Z      X      C      V      B
Thumbs: SUPER    MO(1)  SPACE

[R-Half]
Row 0:  6        7      8      9      0      - / _
Row 1:  Y        U      I      O      P      BACKSPACE
Row 2:  H        J      K      L      ; / :  ' / "
Row 3:  N        M      , / <  . / >  / / ?  SHIFT
Thumbs: ENTER    MO(2)  ALT_GR
```

---

### Layer 1: NAV & DWM & MULTIMÍDIA (Segure Polegar Esquerdo: `MO(1)`)
```text
[L-Half]
Row 0:  ___      PREV   NEXT   PLAY   VOL-   VOL+
Row 1:  ___      MUTE   BRI+   PRTSCR ___    ___
Row 2:  ___      BRI-   ALT    SHIFT  CTRL   SUPER
Row 3:  ___      ___    ___    ___    ___    ___
Thumbs: SUPER    ___    MO(3)

[R-Half]
Row 0:  ___      ___    ___    ___    ___    ___
Row 1:  ___      HOME   PGUP   PGDN   END    DEL
Row 2:  LEFT(H)  DOWN(J)UP(K)  RGHT(L)INS    ___
Row 3:  ___      BSPC   DEL    ___    ___    ___
Thumbs: ENTER    MO(3)  ___
```

---

### Layer 2: SYM - Símbolos de Dev (Segure Polegar Direito: `MO(2)`)
```text
[L-Half]
Row 0:  ~        !      @      #      $      %
Row 1:  ___      (      )      {      }      |
Row 2:  ___      &      *      -      +      =
Row 3:  ___      [      ]      <      >      \
Thumbs: SUPER    MO(3)  SPACE

[R-Half]
Row 0:  ^        &      *      (      )      +
Row 1:  !        :      ?      "      '      BSPC
Row 2:  =        +      -      *      /      :
Row 3:  _        %      ;      .      /      ___
Thumbs: ENTER    ___    ALT_GR
```

---

### Layer 3: NUMPAD & FN & HARDWARE (Segure ambos os polegares: `MO(3)`)
```text
[L-Half]
Row 0:  ___      F1     F2     F3     F4     F5
Row 1:  ___      F6     F7     F8     F9     F10
Row 2:  ___      F11    F12    ___    ___    ___
Row 3:  ___      ___    ___    ___    ___    BOOTLOADER (Flash)
Thumbs: ___      ___    ___

[R-Half]
Row 0:  ___      7      8      9      *      ___
Row 1:  ___      4      5      6      +      ___
Row 2:  ___      1      2      3      -      NUM_ENTER
Row 3:  0        0      .      /      =      ___
Thumbs: NUM_ENTER ___   ___
```

---

### Layer 4: VIM MOUSE & SCROLL & CLIQUES (`TG(4)`: Polegar E + `V` ou `B`)
```text
[L-Half]
Row 0:  SAIR(0)  SNIPER(1) NORMAL(2) TURBO(3)  ___       ___
Row 1:  TAB      ___       SCR_CIMA  SCR_BAIXO ___       ___
Row 2:  SAIR(0)  SNIPER(A) BTN_MEIO  BTN_ESQ   BTN_DIR   BTN_ESQ
Row 3:  SHIFT    VOLTAR(Z) AVAN(X)   F_ABA(C)  N_ABA(V)  SAIR(B)
Thumbs: BTN_ESQ  SAIR(0)   BTN_DIR

[R-Half]
Row 0:  ___      ___       ___       ___       ___       ___
Row 1:  SCR_ESQ  SCR_CIMA  SCR_BAIXO SCR_BAIXO SCR_DIR   BSPC
Row 2:  MS_ESQ(H)MS_BAIX(J)MS_CIMA(K)MS_DIR(L) BTN_ESQ   BTN_DIR
Row 3:  BTN_ESQ  BTN_DIR   BTN_MEIO  VOLTAR(.) AVAN(/)   SAIR(0)
Thumbs: BTN_ESQ  SAIR(0)   BTN_DIR
```

* **Como ativar**: Segure o polegar esquerdo (`MO(1)`) e aperte `V` ou `B`. O teclado entra e trava no modo mouse!
* **Como guiar o mouse**: Mão direita mexe o cursor com `H J K L` (Vim) e rola com `U/I/O` (scroll vertical) e `Y/P` (scroll horizontal).
* **Cliques**:
  * **Clique Esquerdo**: `D`, `G`, `N`, `;` ou **Polegar Esquerdo**.
  * **Clique Direito**: `F`, `M`, `'` ou **Polegar Direito**.
  * **Clique do Meio (abrir links em nova aba)**: Tecla **`S`** ou vírgula **`,`**.
* **Navegação Web Direta**:
  * **Voltar Página** (`Alt + ←`): Tecla **`Z`** (mão esquerda) ou ponto **`.`** (mão direita).
  * **Avançar Página** (`Alt + →`): Tecla **`X`** (mão esquerda) ou barra **`/`** (mão direita).
  * **Fechar Aba** (`Ctrl + W`): Tecla **`C`**.
  * **Nova Aba** (`Ctrl + T`): Tecla **`V`**.
* **Velocidades**: Tecla `A` ou `1` (Sniper / precisão cirúrgica), `2` (Normal), `3` (Turbo).
* **Como sair**: Aperte `Esc`, `Caps Lock`, tecla `B` ou o centro do polegar (`TO(0)`) para voltar na hora à digitação normal.

---

## 🚀 Como Importar no Vial

1. Abra o **Vial** (AppImage ou pelo navegador em [vial.rocks](https://vial.rocks)).
2. Conecte o seu **Squalius-cephalus silakka54**.
3. No menu superior, clique em:
   **File** -> **Load layout...**
4. Selecione o arquivo:
   `silakka54-fabio-vim-dwm.vil` (está na sua pasta **Downloads** ou dentro deste repositório).
5. O Vial aplicará o layout imediatamente!

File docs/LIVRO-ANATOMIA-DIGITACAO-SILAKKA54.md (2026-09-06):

# A Anatomia da Digitação: Da Máquina de Sholes aos Teclados Ergonômicos Divididos e o Silakka54

### *Uma Investigação Histórica, Biomecânica, Linguística e Técnica sobre a Interface Homem-Máquina para Desenvolvedores*

**Autor:** Equipe de Engenharia e Ergonomia de Interfaces  
**Edição Especial de Estudo:** Compatível com NotebookLM, Leitores Digitais e Pesquisa Acadêmica  
**Data:** 2026  

---

## 📖 Prefácio: A Interface Esquecida

Por mais de meio século, a humanidade testemunhou a mais vertiginosa revolução tecnológica da sua história. Os computadores deixaram de ocupar salas inteiras refrigeradas a vácuo para se tornarem supercomputadores de bolso com bilhões de transistores por milímetro quadrado. Telas de fósforo verde deram lugar a painéis OLED de altíssima densidade; linguagens de programação evoluíram do código binário em cartões perfurados para ambientes hiper-abstratos orientados a objetos e sistemas de inteligência artificial generativa.

No entanto, em meio a essa transformação colossal, a ferramenta física primária através da qual o desenvolvedor de software, o escritor e o cientista traduzem seus pensamentos abstratos para a máquina permaneceu rigorosamente congelada no tempo. 

O teclado que repousa sobre a mesa de milhões de profissionais contemporâneos não foi desenhado para a anatomia dos tendões humanos, nem para a digitação de linguagens modernas como Rust, Python ou JavaScript, e muito menos para a sintaxe do Português brasileiro. Ele é o fóssil vivo de uma solução de engenharia mecânica rústica, patenteada em 1868 para resolver o atrito de hastes de metal articuladas que batiam em fitas de tinta sob a força de molas de carruagem.

O custo desse anacronismo é medido diariamente em consultórios de ortopedia e fisioterapia: tenossinovites, síndrome do túnel do carpo, dores crônicas nos trapézios e compressões ulnres que encurtam carreiras brilhantes.

Este livro foi concebido como um compêndio exaustivo para estudantes, desenvolvedores e pesquisadores. Ele traça a linha histórica contínua de 160 anos — dos primeiros protótipos de Christopher Latham Sholes aos teclados divididos contemporâneos baseados em microcontroladores RP2040 rodando firmware Vial, culminando na análise profunda da arquitetura do **Silakka54**. 

Seja bem-vindo a uma jornada onde a história da tecnologia, a medicina ocupacional, a linguística matemática e a engenharia de software convergem.

---

# Sumário Geral

1. **Capítulo 1: A Gênese Mecânica (1868–1930)**
   * 1.1 A invenção de Sholes, Glidden e Soule
   * 1.2 O mito e a realidade do layout QWERTY: A influência telegráfica e mecânica
   * 1.3 A Remington Standard e a introdução da tecla Shift
   * 1.4 A invenção da Digitação às Cegas (*Touch Typing*) e a batalha de Cincinnati (1888)
   * 1.5 O primeiro estudo científico de ergonomia: E. A. Klockenberg (1926)

2. **Capítulo 2: A Era Industrial e as Primeiras Revoluções Ergonômicas (1930–1980)**
   * 2.1 August Dvorak e a biomecânica da década de 1930
   * 2.2 Os testes navais na Segunda Guerra Mundial e a controvérsia de 1956
   * 2.3 O IBM Selectric: A mecanização esférica e a oportunidade perdida
   * 2.4 A revolução radical de Lillian Malt e Stephen Hobday: O PCD Maltron (1977)
   * 2.5 A pesquisa de Karl Kroemer sobre teclados articulados

3. **Capítulo 3: A Epidemia Digital e a Reação Corporativa (1980–2000)**
   * 3.1 O IBM Model M (1985) e a canonização do layout de 101/104 teclas
   * 3.2 A explosão dos computadores pessoais e a epidemia de LER/RSI nos anos 90
   * 3.3 A reação da indústria: Microsoft Natural Keyboard (1994) e Apple Adjustable
   * 3.4 Os pioneiros da geometria de concavidade: Kinesis Contoured (1992) e DataHand (1995)

4. **Capítulo 4: O Renascimento Maker e o Firmware Aberto (2000–Presente)**
   * 4.1 A era dos fóruns (Geekhack, Deskthority) e a desconstrução do teclado comercial
   * 4.2 A revolução do firmware: Hasu, Jack Humbert (QMK), ZMK e Vial
   * 4.3 Taxonomia geométrica: *Row-Stagger*, *Ortholinear* e *Column-Stagger*
   * 4.4 A linhagem dos teclados divididos: Ergodox, Dactyl-ManuForm, Corne e a gênese do Silakka54 de Juho T.

5. **Capítulo 5: Tratado de Biomecânica Ocupacional e Fisiopatologia**
   * 5.1 Anatomia funcional do membro superior humano
   * 5.2 O Desvio Ulnar e a dinâmica de pressão intracanal do carpo (Rempel et al.)
   * 5.3 Pronação do antebraço e a física do *Tenting*
   * 5.4 Extensão do punho e a Lei de Fitts aplicada à *Home Row*
   * 5.5 Assimetria muscular: O grupo tenar do polegar vs. a fragilidade do quinto quirodáctilo
   * 5.6 A neurofisiologia do *Mouse Reach* e a rotação externa do ombro

6. **Capítulo 6: Linguística Computacional, Corpora Textuais e Código**
   * 6.1 Análise de frequência de caracteres e *n-grams* (Monogramas, Bigramas e Trigramas)
   * 6.2 O comportamento singular da língua portuguesa: Acentuação dinâmica e o dígrafo nasal
   * 6.3 Métricas de eficiência: *Same-Finger Bigrams* (SFB) e *Hand Alternation*
   * 6.4 A questão do Cedilha (`ç`): Por que o *Tap-Dance* no `C` falha na programação
   * 6.5 Topologia de operadores para desenvolvedores: A geometria dos delimitadores de sintaxe

7. **Capítulo 7: A Filosofia das Camadas Virtuais e a Simbiose com Linux/Vim**
   * 7.1 O paradoxo de volume: Como 54 teclas realizam mais trabalho físico que 104
   * 7.2 Tipos de transição de camada: Momentary (`MO`), Toggle (`TG`) e To (`TO`)
   * 7.3 Arquitetura de modais no Vim e Gerenciadores de Janela em Mosaico (DWM)
   * 7.4 O modificador mestre (*Super/Mod4*) no polegar e o CapsLock híbrido (*Dual-Role*)
   * 7.5 A emulação de mouse em hardware (Layer 4): Navegação contínua sem quebra postural

8. **Capítulo 8: Especificações Técnicas de Engenharia do Silakka54**
   * 8.1 Arquitetura do microcontrolador RP2040 (Raspberry Pi Silicon)
   * 8.2 Matriz de escaneamento de teclas, diodos anti-ghosting e NKRO
   * 8.3 O protocolo Vial: Estrutura da EEPROM virtual e carregamento dinâmico
   * 8.4 Mapeamento completo e fundamentado das 5 camadas do Silakka54

9. **Capítulo 9: Neurobiologia da Memória Motora e Protocolos de Treinamento**
   * 9.1 Gânglios da base, cerebelo e a mielinização dos circuitos de digitação
   * 9.2 Superando o vale da desilusão na transição para o layout colunar
   * 9.3 Métodos de treino deliberado: Frequência, acurácia e o papel dos simuladores

10. **Capítulo 10: Glossário e Referências Bibliográficas Científicas**

---

# Capítulo 1: A Gênese Mecânica (1868–1930)

### 1.1 A invenção de Sholes, Glidden e Soule
Em 1868, na cidade de Milwaukee, Wisconsin, o jornalista, impressor e inventor **Christopher Latham Sholes**, em parceria com **Carlos Glidden** e **Samuel W. Soule**, obteve a patente norte-americana de número US 79.868 para uma máquina projetada para numerar páginas de livros e, em seguida, transcrever caracteres alfabéticos por meios puramente mecânicos.

A máquina original era operada como um pequeno piano de brinquedo. As teclas eram organizadas em duas fileiras de botões feitos de marfim e madeira, dispostos em ordem estritamente alfabética:
```text
  - 3 5 7 9 N O P Q R S T U V W X Y Z
  2 4 6 8 . A B C D E F G H I J K L M
```
O princípio funcional dessa máquina continha a semente de todos os problemas que a humanidade enfrentaria no século seguinte. Cada tecla acionava uma haste metálica longa (*typebar*), em cuja ponta estava gravado o relevo invertido de um caractere. Ao ser pressionada, a haste girava verticalmente de baixo para cima dentro de uma cesta circular, colidindo contra uma fita embebida em tinta e pressionando o papel contra uma chapa de borracha cilíndrica (*platen*).

### 1.2 O mito e a realidade do layout QWERTY
Existe um mito persistente na cultura popular segundo o qual o layout QWERTY foi concebido deliberadamente para "reduzir a velocidade dos operadores", porque as pessoas digitavam rápido demais para a máquina. 

A historiografia moderna da tecnologia, em especial as pesquisas conduzidas por historiadores da Universidade de Quioto (Yasuoka & Yasuoka, 2011), refuta essa narrativa simplista. O layout QWERTY não foi desenhado para "atrapalhar o ser humano", mas sim para contornar uma limitação estritamente cinemática da cesta mecânica de tipos articulados.

Quando duas hastes vizinhas na cesta circular eram acionadas em rápida sucessão, a gravidade e o retorno de mola eram lentos demais para puxar a primeira haste para baixo antes que a segunda subisse. O resultado era a colisão física e o travamento inextrincável das duas hastes no ponto de convergência.

Para solucionar isso, Sholes e seus associados analisaram quais pares de letras (bigramas) eram mais comuns na língua inglesa (`TH`, `ST`, `RE`, `ER`, `IN`, `ON`). Eles redistribuíram as teclas na cesta de modo que as letras de bigramas frequentes ficassem localizadas em extremidades opostas do semicírculo mecânico. 

Adicionalmente, os primeiros operadores das máquinas de Sholes eram telegrafistas que transcreviam código Morse sonoro diretamente para o papel impresso. No código Morse, certas sequências de pontos e traços eram ambíguas (por exemplo, a combinação de sons entre as letras `Z`, `S` e `E`). O layout foi iterado experimentalmente para permitir que o telegrafista pudesse bater teclas sem tropeçar na decodificação do sinal telegráfico.

Por volta de 1873, o layout havia convergido para o formato que hoje conhecemos como **QWERTY**:
```text
  1 2 3 4 5 6 7 8 9 0 - =
   Q W E R T Y U I O P [ ]
    A S D F G H J K L ; '
     Z X C V B N M , . /
```

### 1.3 A Remington Standard e a introdução da tecla Shift
Em 1873, Sholes vendeu a patente e os direitos de manufatura da máquina para a **E. Remington and Sons**, tradicional fabricante de armas de fogo e máquinas de costura de Ilion, Nova York, que buscava diversificar sua linha de produção após a Guerra Civil Americana.

A Remington aplicou seu maquinário de precisão metalúrgica para lançar a **Remington No. 1** em 1874. A máquina, contudo, imprimia apenas letras maiúsculas. Foi somente em 1878, com a lendária **Remington No. 2**, que surgiu um mecanismo revolucionário: a tecla **Shift**.

Em vez de dobrar o número de teclas para incluir minúsculas (o que tornaria o teclado impossivelmente largo), cada haste de metal passou a carregar dois relevos sobrepostos: a letra minúscula abaixo e a maiúscula acima. Ao pressionar a tecla `Shift`, todo o carro mecânico contendo o papel e o rolo cilíndrico era erguido fisicamente por alguns milímetros, fazendo com que a haste atingisse o papel na posição da maiúscula. 

O esforço mecânico necessário para levantar um bloco maciço de ferro a cada letra maiúscula determinou que a tecla `Shift` precisasse de uma mola pesada, e o dedo mindinho — situado na borda externa — foi o escolhido para empurrar essa alavanca. Esse arranjo acidental de 1878 sobrecarrega o dedo mais fraco da mão humana até hoje.

### 1.4 A invenção da Digitação às Cegas e o Concurso de Cincinnati (1888)
Nos primeiros vinte anos da máquina de escrever, todos os operadores utilizavam a técnica visual de caçar teclas com dois ou quatro dedos (*hunt and peck*). Não se acreditava que fosse possível digitar sem olhar continuamente para o teclado.

Essa realidade mudou em 1888, na cidade de Cincinnati, Ohio, quando ocorreu um concurso público de digitação de velocidade entre **Frank Edward McGurrin**, um escrivão judicial de Salt Lake City, e **Louis Traub**, um renomado digitador com quatro dedos.

McGurrin havia passado anos memorizando a posição espacial absoluta das teclas na Remington No. 2 e desenvolvido uma disciplina cinestésica rigorosa: suas mãos repousavam sobre a linha central (`ASDF` para a mão esquerda, `HJKL` para a mão direita), que passou a ser chamada de **Home Row** (linha de descanso). Ele digitava lendo o texto de relance sem jamais olhar para suas mãos.

McGurrin destruiu Traub na competição, digitando a uma velocidade sem precedentes de mais de 90 palavras por minuto. A vitória teve repercussão estrondosa na imprensa mundial. Da noite para o dia, o método de digitação às cegas (*touch typing*) de McGurrin tornou-se a norma universal em escolas comerciais de secretariado. Ao consagrar a técnica de McGurrin, o mundo corporativo congelou o QWERTY como o padrão de fato que nenhuma tecnologia subsequente conseguiu derrubar.

### 1.5 O primeiro estudo científico de ergonomia: E. A. Klockenberg (1926)
Apesar do sucesso comercial avassalador, os operadores da época começaram a apresentar dores crônicas nos pulsos e ombros. Em 1926, na Alemanha pós-Primeira Guerra, o engenheiro e pesquisador **E. A. Klockenberg** publicou a obra inaugural da ergonomia de digitação:  
*Rationalisierung der Schreibmaschine und ihrer Bedienung* ("A Racionalização da Máquina de Escrever e sua Operação").

Klockenberg foi o primeiro cientista a fotografar e medir os ângulos dos membros superiores durante a digitação. Suas conclusões foram demolidoras:
1. Uma superfície retangular única obriga os punhos a se dobrarem lateralmente em direção ao dedo mínimo (**desvio ulnar**).
2. Manter os braços juntos força a rotação dos ossos do antebraço (**pronação**), gerando tensão muscular estática contínua nos ombros.
3. Klockenberg propôs formalmente dividir a máquina de escrever em **duas metades separadas**, anguladas lateralmente para fora em um formato de "V", permitindo que os braços operassem a partir da linha natural dos ombros.

A indústria da década de 1920, contudo, ignorou as recomendações de Klockenberg. O ferramental industrial estava solidificado em torno do chassi reto de ferro fundido, e alterar as linhas de montagem seria financeiramente impensável.

---

# Capítulo 2: A Era Industrial e as Primeiras Revoluções Ergonômicas (1930–1980)

### 2.1 August Dvorak e a biomecânica da década de 1930
Na década de 1930, o professor de educação da Universidade de Washington, **Dr. August Dvorak**, e seu cunhado, o Dr. William Dealey, realizaram o primeiro estudo linguístico e temporal exaustivo sobre a distribuição de frequência das letras no idioma inglês.

Financiados pela Fundação Carnegie, Dvorak e Dealey filmaram milhares de horas de digitação em câmera lenta, medindo os tempos de reação entre diferentes dedos e mapeando os padrões de movimento. Suas constatações sobre o layout QWERTY foram estarrecedoras:
* No QWERTY, apenas **32% da digitação** ocorre na linha de repouso (*Home Row*). O usuário passa 52% do tempo esticando os dedos para a linha superior e 16% para a linha inferior.
* A mão esquerda (não dominante para 90% da população) realiza **56% de todo o trabalho físico**.
* Milhares de palavras comuns em inglês exigem o uso repetido do mesmo dedo em teclas consecutivas (*Same-Finger Bigrams*), o que reduz a velocidade em até 40%.

Em 1936, Dvorak patenteou o **Dvorak Simplified Keyboard (DSK)**:
```text
  [ ] ' , . P Y F G C R L / =
   A O E U I D H T N S -
    ; Q J K X B M W V Z
```
Os princípios de Dvorak eram matematicamente elegantes:
1. **Todas as cinco vogais principais (`A, O, E, U, I`)** foram colocadas na mão esquerda da *Home Row*, enquanto as consoantes mais frequentes (`D, H, T, N, S`) foram colocadas na mão direita.
2. Como quase toda sílaba requer ao menos uma vogal e uma consoante, a digitação em Dvorak maximiza a **alternância estrita de mãos**: enquanto uma mão bate a vogal, a outra já está no ar acelerando em direção à consoante.
3. Na *Home Row* do Dvorak ocorrem impressionantes **70% de todas as batidas de teclas**, reduzindo o deslocamento espacial dos dedos em até 67% ao longo de um dia de trabalho.

```text
DISTRIBUIÇÃO DE CARGA NA HOME ROW:
  QWERTY: [==== 32% ====]
  DVORAK: [================ 70% ================]
```

### 2.2 Os testes navais na Segunda Guerra Mundial e a controvérsia de 1956
Durante a Segunda Guerra Mundial, a Marinha dos Estados Unidos realizou experimentos práticos com operadores de rádio e teletipos, treinando grupos no layout Dvorak. Os relatórios iniciais indicaram que os digitadores treinados no layout de Dvorak alcançavam entre 68% e 74% de aumento de velocidade, com 70% menos erros e muito menor relato de fadiga.

Entretanto, em 1956, o economista da General Services Administration (GSA), **Earle Strong**, conduziu um contra-estudo governamental que concluiu que o custo financeiro de retreinar secretárias em todo o país não compensava os ganhos de produtividade. Décadas mais tarde, pesquisadores acadêmicos revelaram que o estudo de Strong foi conduzido de forma enviesada, com tempo de retreinamento insuficiente e clara intenção de proteger o investimento do governo nos milhões de máquinas QWERTY existentes. O bloqueio institucional contra a mudança consolidou-se em definitivo.

### 2.3 O IBM Selectric: A mecanização esférica e a oportunidade perdida
Em 1961, a IBM lançou a máquina de escrever mais bem-sucedida da história corporativa mundial: a **IBM Selectric**. 

Engenhosamente desenhada por Eliot Noyes, a Selectric eliminou por completo a cesta circular de hastes articuladas. Em seu lugar, introduziu a famosa "esfera de tipos" (*typeball*, carinhosamente chamada de *golf ball*). A esfera girava e se inclinava a velocidades estonteantes antes de colidir contra a fita de tinta, movendo-se ao longo da página enquanto o papel permanecia fixo.

Com a Selectric, **o motivo mecânico original do QWERTY havia desaparecido por completo**. Não havia mais hastes para colidir ou emperrar. A IBM poderia ter adotado o layout Dvorak ou introduzido o teclado dividido de Klockenberg sem qualquer restrição física.

No entanto, a inércia da base instalada falou mais alto. O mundo contava com milhões de secretárias e escolas de datilografia totalmente condicionadas ao QWERTY. A IBM optou por manter o layout padrão de 1873 inalterado, transportando os vícios da mecânica vitoriana para a alvorada da era da computação eletrônica.

### 2.4 A revolução radical de Lillian Malt e Stephen Hobday: O PCD Maltron (1977)
Enquanto a indústria convencional se acomodava, uma especialista britânica em treinamento de datilografia chamada **Lillian Malt** começou a investigar a fundo os limites da biomecânica da mão. Malt trabalhava com operadores do sistema Linotype na indústria gráfica e via diariamente o desgaste físico extremo desses profissionais.

Malt concluiu que mudar apenas a ordem das letras (como Dvorak fizera) em uma prancha plana de plástico não resolvia a raiz do sofrimento físico. Ela compreendeu que:
1. Os dedos humanos **possuem comprimentos dramaticamente diferentes** (o dedo médio é muito mais longo que o mínimo ou o indicador).
2. Os dedos **flexionam em arcos naturais**, e não em movimentos perpendiculares planos.
3. Os polegares humanos eram grotescamente subutilizados.

Em 1974, Malt uniu forças com o engenheiro de circuitos eletrônicos **Stephen Hobday**, fundador da *Printed Circuit Design Ltd.*. Juntos, em **1977**, fundaram a **PCD Maltron Ltd.** e apresentaram ao mundo o primeiro teclado de alta ergonomia já concebido: o **Maltron Keyboard**.

```text
O CONCEITO MALTRON (1977):
    [Mão Esquerda]                     [Mão Direita]
  (Poço Côncavo 3D)                  (Poço Côncavo 3D)
  Colunas Verticais                  Colunas Verticais
         \                                  /
          \                                /
           [Thumb Cluster]  [Thumb Cluster]
           (Espaço, Enter,  (Backspace, Del,
            Shift, E, etc.)  Layers, etc.)
```

O design do Maltron foi décadas à frente de seu tempo:
* **Poços Côncavos Tridimensionais (*3D Key Wells*)**: As teclas ficavam montadas no interior de duas bacias curvas, acompanhando o raio de alcance natural dos dedos.
* **Colunas Retas (*Column-Stagger*)**: As teclas não tinham o degrau horizontal torto de 1873. Elas eram alinhadas em colunas perfeitamente verticais, com a profundidade ajustada à altura anatômica de cada dedo.
* **Clusters de Polegar (*Thumb Clusters*)**: Pela primeira vez na história, cada polegar recebeu um conjunto de 8 teclas dedicadas, assumindo tarefas vitais como `Backspace`, `Enter`, `Shift` e até letras frequentes como a letra `E`.

O Maltron tornou-se a referência máxima para a reabilitação de digitadores severamente lesionados por LER. Ele provou que um teclado projetado do zero em torno da fisiologia humana permitia jornadas inteiras de trabalho sem dor.

### 2.5 A pesquisa de Karl Kroemer sobre teclados articulados
Paralelamente aos desenvolvimentos de Malt, o Dr. **Karl H. E. Kroemer**, pesquisador dos Laboratórios de Pesquisa Médica Aeroespacial da Força Aérea dos Estados Unidos, conduziu experimentos fundamentais em 1972 com protótipos de teclados bipartidos com articulação esférica central. 

Kroemer estabeleceu que a rotação lateral (abertura em leque de 30° a 50°) somada à inclinação vertical (*tenting* de 45°) reduzia a atividade mioelétrica medida por eletromiografia (EMG) nos músculos do trapézio para quase zero durante a digitação estática. Seus artigos assentaram as bases científicas da geometria ergonômica moderna.

---

# Capítulo 3: A Epidemia Digital e a Reação Corporativa (1980–2000)

### 3.1 O IBM Model M (1985) e a canonização do padrão de 101/104 teclas
Em 1985, a IBM lançou seu teclado definitivo para a linha de computadores pessoais IBM PC/AT: o lendário **Model M**. 

Tecnicamente, o Model M era uma obra-prima de engenharia mecânica. Ele introduziu o sistema patenteado de molas de torção em flambagem (*buckling spring*), que fornecia uma resposta tátil e sonora inigualável: ao ser pressionada, a mola interna encurvava-se repentinamente sob tensão elástica, acionando uma membrana de carbono com precisão absoluta.

No entanto, do ponto de vista ergonômico, o Model M cometeu um pecado histórico imperdoável: ele **canonizou a arquitetura retangular monolítica e estendida de 101 a 104 teclas**, dividida em três blocos rígidos:
1. O bloco alfanumérico com colunas em degraus (*row-stagger* herdado de Sholes).
2. O bloco de navegação intermediário (setas invertidas em "T" e bloco de seis teclas `Insert`, `Home`, `Page Up`, etc.).
3. O teclado numérico estendido (*Numpad*) à direita.

```text
ARQUITETURA IBM MODEL M (1985):
+------------------------------------+ +-----------+ +---------------+
|       Bloco Alfanumérico           | | Navegação | |    Numpad     |
| (Desvio Ulnar + Mindinho Castigado)| |  (Setas)  | |  (Calculadora)|
+------------------------------------+ +-----------+ +---------------+
                                                       \
                                                        --> [MOUSE AQUI]
                                                       (Braço Hiperestendido!)
```

Para dar espaço ao Numpad integrado à direita, o Model M media cerca de **49 centímetros de largura**. Quando a interface gráfica do Windows e do Macintosh explodiu na década de 1990 exigindo o uso constante do mouse, o mouse foi empurrado para o extremo da mesa, a quase meio metro de distância da linha de descanso do digitador. O palco para uma crise médica sem precedentes estava montado.

### 3.2 A explosão dos computadores pessoais e a epidemia de LER/RSI
No início da década de 1990, o computador pessoal substituiu a máquina de escrever em todos os escritórios corporativos, bancos, agências de notícias e empresas de engenharia do planeta. Ao contrário da máquina de escrever, onde o datilógrafo pausava a cada minuto para trocar o papel, empurrar a alavanca do carro e virar páginas físicas, o usuário do PC permanecia horas ininterruptas em digitação estática contínua e frenética.

Entre 1990 e 1998, as notificações de **Lesões por Esforço Repetitivo (LER / RSI - *Repetitive Strain Injury*)** e **Síndrome do Túnel do Carpo (STC)** explodiram nas estatísticas do Departamento de Trabalho dos EUA (OSHA) e do Ministério da Saúde no Brasil. Empresas de jornalismo e tecnologia viram milhares de profissionais afastados por invalidez temporária ou permanente. Processos judiciais milionários começaram a ser movidos contra fabricantes de computadores.

### 3.3 A reação da indústria: Microsoft Natural Keyboard e Apple Adjustable
Diante da ameaça de regulação médica rigorosa, as gigantes da tecnologia tiveram que responder.

Em 1993, a Apple introduziu o **Apple Adjustable Keyboard**, um teclado pioneiro de membrana dividido em duas metades ajustáveis em ângulo horizontal, acompanhado de um bloco de descanso de punho acolchoado.

Em 1994, a Microsoft lançou o produto de hardware de maior sucesso de sua história até então: o **Microsoft Natural Keyboard**, projetado pelo designer Ken Zierick e sua equipe.
* O chassi plástico era curvado em um formato de "asa de gaivota".
* As teclas alfanuméricas eram fisicamente divididas em dois blocos angulados para fora em 12° e inclinados para cima no centro (*tenting* leve de 8°).
* Ele vinha com um apoio de punhos integrado de plástico texturizado.

O Microsoft Natural Keyboard vendeu milhões de unidades e colocou a palavra "ergonomia" no vocabulário popular de escritórios em todo o mundo. Ele comprovou que o mercado de massa aceitava teclados não retangulares. No entanto, o Natural Keyboard era um paliativo: ele ainda mantinha as colunas tortas em degraus (*row-stagger*), a barra de espaço longa e o Numpad empurrando o mouse para longe.

### 3.4 Os pioneiros radicais: Kinesis Contoured e DataHand
Enquanto a Microsoft atendia ao mercado intermediário corporativo, duas empresas levaram a lição do Maltron de 1977 para a vanguarda tecnológica dos anos 90:

1. **Kinesis Corporation e o Contoured Keyboard (1992)**:
   Fundada em Bellevue, Washington, por Will Hargreaves, a Kinesis lançou o **Kinesis Model 100** (que evoluiria para o celebrado **Kinesis Advantage**). O Kinesis adotou abertamente poços côncavos profundos de plástico, colunas verticais ortolineares e separou os botões mais pesados (`Backspace`, `Delete`, `Enter`, `Space`, `Ctrl`, `Alt`) em **dois clusters de polegar em formato de leque**. Tornou-se o teclado padrão absoluto entre engenheiros da NASA, administradores de sistemas Unix e programadores com lesões graves.

2. **O DataHand System (1995)**:
   Criado por Dale Retter, o DataHand representou a desconstrução mais radical de um teclado na história humana. Ele eliminou completamente as teclas convencionais. O usuário descansava as mãos em duas conchas moldadas; cada um dos 10 dedos encaixava-se em um berço com 5 micro-chaves ópticas ativadas por minúsculos deslocamentos de 1 a 2 milímetros em quatro direções (para frente, para trás, para a esquerda, para a direita) e pressão central. Embora eliminasse 99% do esforço muscular, seu custo astronômico e curva de aprendizado brutal impediram a adoção em larga escala.

---

# Capítulo 4: O Renascimento Maker e o Firmware Aberto (2000–Presente)

### 4.1 A era dos fóruns e a desconstrução do teclado comercial
No final da década de 2000, um grupo global de engenheiros de software, designers de hardware e entusiastas percebeu que as grandes marcas haviam estagnado. Os teclados comerciais tornaram-se produtos plásticos descartáveis de membrana barata.

Através de comunidades digitais como o **Geekhack** (fundado em 2002), o **Deskthority** e o fórum `r/MechanicalKeyboards` do Reddit, uma contracultura de engenharia começou a florescer. Usuários resgatavam antigos switches mecânicos dos anos 80, encomendavam placas de circuito impresso personalizadas (*PCBs*) e cortavam placas de suporte de aço e acrílico a laser em pequenas oficinas de prototipagem.

### 4.2 A revolução do firmware: Hasu, Jack Humbert (QMK), ZMK e Vial
O ponto de inflexão definitivo da história dos teclados mecânicos não foi o hardware, mas sim **a libertação do software**:

1. **TMK Keyboard Firmware (Hasu, 2011)**: O desenvolvedor japonês conhecido como Hasu escreveu um firmware livre em C para microcontroladores Atmel AVR (como o ATmega32U4 do Arduino Pro Micro). Pela primeira vez, a lógica de funcionamento do teclado deixava de ser uma caixa preta proprietária da controladora de fábrica.
2. **QMK Firmware (Quantum Mechanical Keyboard, Jack Humbert, 2015)**: Criador da *OLKB* e do minúsculo teclado ortolinear Planck de 40 teclas, Jack Humbert bifurcou o TMK e fundou o **QMK**. O QMK tornou-se o sistema operacional universal dos teclados customizados no mundo. Ele trouxe abstrações avançadas: camadas dinâmicas infinitas, chaves de dupla função (*tap-dance*, *mod-tap*), macros em memória flash e processamento direto na controladora.
3. **ZMK Firmware**: Desenvolvido em linguagem moderna sobre o RTOS Zephyr, voltado especificamente para teclados divididos sem fio baseados em Bluetooth Low Energy (BLE) com microcontroladores nRF52840.
4. **Vial (xyz, 2021)**: Um avanço extraordinário sobre o QMK. Historicamente, qualquer alteração em uma tecla no QMK exigia reeditar arquivos de código em C, recompilar o arquivo binário `.hex` ou `.uf2` e gravá-lo no microcontrolador via bootloader. O Vial implementou um protocolo em tempo real seguro: a estrutura de dados das teclas é lida e escrita diretamente na **EEPROM virtual/Flash do microcontrolador**. O usuário abre uma interface gráfica (nativa ou via WebUSB no navegador), arrasta uma tecla, e ela passa a funcionar no milissegundo seguinte, sem recompilação.

### 4.3 Taxonomia geométrica: Row-Stagger, Ortholinear e Column-Stagger
A comunidade de engenharia estabeleceu uma taxonomia dimensional rigorosa para categorizar a disposição espacial das matrizes de teclas:

```text
1. ROW-STAGGER (Tradicional de 1873):
   [   Q   ][   W   ][   E   ]   <- Degraus horizontais assimétricos
     [   A   ][   S   ][   D   ] <- Exige torção lateral dos dedos
       [   Z   ][   X   ][   C   ]

2. ORTHOLINEAR PURO (Grid - Ex: Planck):
   [ Q ][ W ][ E ] <- Grade matemática perfeitamente retangular
   [ A ][ S ][ D ] <- Ótimo para lógica, mas dedos humanos
   [ Z ][ X ][ C ]    têm comprimentos desiguais!

3. COLUMN-STAGGER (Ergonômico Natural - Ex: Silakka54, Corne):
          [ W ]
   [ Q ]  [ S ]  [ E ]  <- As colunas são verticalmente deslocadas
   [ A ]  [ X ]  [ D ]  <- Casam milimetricamente com a diferença
   [ Z ]         [ C ]     de tamanho entre mindinho, anelar e médio!
```

* **Row-Stagger**: O padrão convencional. Completamente anti-anatômico. O dedo médio ao descer para o `C` precisa cruzar por trás do indicador.
* **Ortholinear (Grade Pura)**: Organizado em linhas e colunas de 90°. Muito superior ao row-stagger, mas desconsidera que o dedo médio é cerca de 2 centímetros mais longo que o dedo mínimo.
* **Column-Stagger (Ergonômico Colunar)**: As colunas são individualmente deslocadas para cima ou para baixo para refletir a anatomia real dos cinco ossos metacarpos e falanges.

### 4.4 A linhagem dos teclados divididos e a gênese do Silakka54
A partir de 2012, uma linhagem gloriosa de designs abertos transformou o cenário global:
* **Ergodox (2012, Dox)**: O pioneiro de código aberto montado em PCB dividida com chips Teensy.
* **Dactyl e Dactyl-ManuForm (Matthew Adereth e Tom Short)**: A fusão do conceito Maltron/Kinesis impresso em 3D com a parametrização em código Clojure.
* **CRKBD / Corne Keyboard (foostan, 2018)**: O designer japonês foostan desenhou uma obra-prima de 42 teclas ultracompacta com displays OLED e LEDs RGB que se tornou o split mais montado do planeta.
* **Lily58 e Sofle (2019-2020)**: Adicionaram a linha de números física para quem não conseguia se adaptar às 42 teclas do Corne.

#### A Gênese do Silakka54 (Juho T. / Squalius-cephalus)
Na Finlândia, o designer de hardware de código aberto **Juho T.** (conhecido pelo pseudônimo *Squalius-cephalus*) analisou os pontos fortes e as carências do Corne e do REVIUNG41. Juho percebeu que muitos desenvolvedores no ambiente Linux e usuários de sistemas de janelas em mosaico queriam a pureza ergonômica colunar e o suporte a clusters de polegar eficientes, mas precisavam de uma **linha de números dedicada** (54 teclas no total) para tags de workspaces, sem abrir mão de um design extremamente compacto e acessível.

Batizado com a palavra finlandesa para a arenque-do-báltico (*Silakka*), o **Silakka54** foi concebido com uma engenharia de ponta:
* PCB reversível inteligente (a mesma placa atende ao lado esquerdo e direito ao ser virada).
* Compatibilidade nativa com soquetes hot-swap Kailh para troca imediata de switches mecânicos.
* Baseado no novíssimo e ultra-poderoso microcontrolador **RP2040 Zero**.
* Suporte de fábrica para firmware **QMK e protocolo Vial**.

---

# Capítulo 5: Tratado de Biomecânica Ocupacional e Fisiopatologia

### 5.1 Anatomia funcional do membro superior humano
O complexo musculoesquelético que controla os movimentos da mão é uma das maravilhas da evolução biomecânica. Ele é composto por três nervos periféricos primários oriundos do plexo braquial:
1. **Nervo Mediano**: Passa pelo túnel do carpo sob o retináculo dos flexores. Inerva os tendões dos dedos polegar, indicador, médio e a metade radial do anelar. É o nervo responsável pela sensibilidade tátil mais fina e pela motricidade de oposição da mão.
2. **Nervo Ulnar**: Percorre a face interna do cotovelo (túnel cubital) e o canal de Guyon no punho. Inerva o quinto dedo (mindinho), metade do anelar e a maioria dos músculos intrínsecos lumbricais e interósseos.
3. **Nervo Radial**: Inerva a musculatura extensora dorsal do antebraço.

```text
CORTE TRANSVERSAL DO TÚNEL DO CARPO:
             [ Retináculo dos Flexores ]
    ---------------------------------------------
   |   (N) Nervo Mediano (Comprimido na STC!)    |
   |                                             |
   |  (T) (T) (T) (T)  Tendões Flexores          |
   |  (T) (T) (T) (T)  Superficiais e Profundos  |
   |        (T)        Tendão Flexor Longo Pol.  |
    ---------------------------------------------
               [ Ossos do Carpo ]
```

### 5.2 O Desvio Ulnar e a dinâmica de pressão intracanal do carpo
Quando as mãos trabalham juntas em um teclado reto padrão, o punho assume uma angulação externa denominada **desvio ulnar**.

Em pesquisas biomecânicas rigorosas, **Rempel et al. (2007)**, **Simoneau & Marklin (1999)** e **Seradge et al. (1995)** introduziram cateteres de pressão hidrostática minúsculos diretamente no canal do carpo de voluntários vivos durante a digitação:
* Em repouso com o punho em posição neutra (desvio ulnar de 0° e flexão de 0°), a pressão intracanal basal situa-se entre **8 e 12 mmHg**.
* Quando o usuário assume o desvio ulnar forçado de 15° a 25° exigido por um teclado convencional de peça única, a pressão salta para **32 a 45 mmHg**.

**O limiar crítico patológico**: A fisiologia médica estabelece que uma pressão tissular contínua acima de **30 mmHg** colapsa os capilares venosos intraneurais e arteríolas nutricionais do nervo mediano. A falta de oxigenação (*isquemia*) provoca edema celular inflamatório, parestesia (formigamento), dor aguda noturna e degeneração axonal progressiva: é a formação clássica da **Síndrome do Túnel do Carpo (STC)**.

O teclado dividido Silakka54 erradica essa causa pela raiz. Ao separar as duas metades na linha dos ombros do usuário, o desvio ulnar é fixado cirurgicamente em **0°**, mantendo a pressão no túnel do carpo em seus níveis mínimos fisiológicos saudáveis.

### 5.3 Pronação do antebraço e a física do Tenting
O rádio e a ulna são conectados pela membrana interóssea do antebraço. Quando as palmas das mãos são forçadas a ficar 100% paralelas ao tampo da mesa (pronação completa a 90°), o osso rádio cruza completamente por cima da ulna.

Essa torção óssea permanente mantém os músculos **pronador redondo** e **pronador quadrado** em estado de contração isométrica crônica, gerando dor referida que irradia até o epicôndilo medial e a articulação escápulo-torácica.

A elevação do centro do teclado divido (*tenting* de 10° a 25°) restaura a posição anatômica natural do aperto de mão (*handshake position*). A musculatura do antebraço relaxa imediatamente, reduzindo a fadiga global da jornada de trabalho.

```text
PRONAÇÃO (Teclado Reto):         TENTING / REPOUSO (Silakka54):
      Rádio cruza a Ulna              Rádio e Ulna Paralelos
       [  MÃO PLANA  ]                     /  MÃO ABERTA  \
       (Tensão Muscular)                 (Relaxamento Total)
```

### 5.4 Extensão do punho e a Lei de Fitts aplicada à Home Row
A **extensão do punho** (dorsiflexão — quando as pontas dos dedos apontam para cima enquanto a base do punho descansa sobre a mesa) tensiona severamente o retináculo dos flexores e reduz o espaço livre para a passagem dos tendões digitais.

Somado a isso, a **Lei de Fitts (Paul Fitts, 1954)** dita o comportamento neuromotor humano:
$$\text{MT} = a + b \log_2 \left( \frac{2D}{W} \right)$$
Onde:
* $\text{MT}$ é o tempo de movimento (*Movement Time*).
* $D$ é a distância que o dedo precisa viajar da sua posição de descanso até o centro da tecla.
* $W$ é o tamanho efetivo da tecla-alvo.

Quando um programador precisa esticar a mão inteira para o canto superior direito do teclado comum para digitar `=` ou `+`, $D$ é gigantesco (mais de 12 a 15 centímetros de deslocamento articular). Pela Lei de Fitts, o tempo motor cresce de forma logarítmica e a variabilidade do sinal neurológico faz a taxa de erro (*typos*) subir exponencialmente.

No Silakka54, através das **camadas de polegar**, os operadores `=`, `+`, `-`, `*`, `( )`, `{ }` situam-se na **Home Row** sob o mesmo indicador ou médio. A distância física $D$ cai para **zero**. O resultado prático é uma velocidade de disparo imediata e ausência total de estiramento tendinoso.

### 5.5 Assimetria muscular: O grupo tenar do polegar vs. o quinto quirodáctilo
A biomecânica comparativa revela a gritante injustiça do teclado convencional:

```text
MASSA MUSCULAR COMPARADA:
  Polegar (Eminência Tenar): [==================== 100% ====================]
  Mindinho (Hipotênar):       [=== 15% ===]
```

O polegar humano é dotado de uma articulação selar carpo-metacárpica extraordinariamente estável, movida pelo músculo abdutor curto do polegar, flexor curto do polegar, oponente do polegar e adutor do polegar. Ele é o pilar anatômico que permitiu à humanidade segurar ferramentas, arremessar lanças e construir civilizações.

Já o quinto quirodáctilo (dedo mindinho) possui uma estrutura óssea fina, tendões longos com polias frágeis e musculatura intrínseca hipotenar minúscula. No entanto, no teclado convencional, o mindinho é incumbido de suportar as teclas mais violentas e frequentes do sistema operacional: `Shift`, `Ctrl`, `Enter`, `Backspace`, `Tab` e `Caps`.

O Silakka54 restabelece a justiça biomecânica:
* **Os dois polegares** dividem o trabalho pesado: `Espaço`, `Enter`, `Super (Mod4)`, `AltGr` e a ativação das **Camadas 1 e 2**.
* Os dedos mindinhos descansam protegidos, operando quase que exclusivamente suas letras designadas de baixo impacto.

### 5.6 A neurofisiologia do Mouse Reach e a rotação externa do ombro
Sempre que um desenvolvedor tira a mão direita do teclado para segurar o mouse tradicional à direita do Numpad:
1. O músculo **deltoide** realiza abdução do braço de 30° a 45°.
2. O músculo **infraespinhal** e o **redondo menor** sustentam a rotação externa do ombro em contração estática sem apoio.
3. Ocorre tração contínua sobre as vértebras cervicais C5 a C7 e sobre a musculatura do **elevador da escápula**.

A repetição desse gesto milhares de vezes ao dia causa a chamada *Síndrome do Ombro do Usuário de Mouse*. 

Ao implementar o **Modo Mouse na Layer 4 via Vim (`HJKL`) diretamente nas teclas físicas**, o desenvolvedor elimina a necessidade de retirar as mãos da postura neutra para 80% das interações da interface gráfica (clicar em botões de confirmação, seguir links, alternar abas, rolar artigos e selecionar textos). O ombro permanece perfeitamente relaxado ao longo de todo o dia.

---

# Capítulo 6: Linguística Computacional, Corpora Textuais e Código

### 6.1 Análise de frequência de caracteres e n-grams
A engenharia moderna de layouts de teclado baseia-se na análise matemática de grandes coleções de textos digitalizados (*corpora*). A análise extrai frequências absolutas e relativas de três métricas primárias:
1. **Monogramas**: A probabilidade isolada de ocorrência de uma letra.
2. **Bigramas**: A frequência de pares de caracteres adjacentes (ex: `QU`, `CH`, `ÃO`, `DE`, `TE`).
3. **Trigramas e Skipgrams**: Sequências de três letras ou pares separados por um caractere intermediário.

Na língua portuguesa, as letras mais frequentes obedecem a uma ordem muito distinta do inglês:
```text
Português: E > A > O > S > R > I > N > D > M > T > U > C > L > P > V > G
Inglês:    E > T > A > O > I > N > S > H > R > D > L > C > U > M > W > F
```
Nota-se que as três primeiras letras em português (`E`, `A`, `O`) são **todas vogais** e representam, sozinhas, quase **38% de todo o vocabulário nacional**.

### 6.2 O comportamento singular da língua portuguesa: Acentuação e nasalidade
O Português impõe um desafio de design de interfaces inexistente na língua inglesa pura: a pesadíssima carga diacrítica (acentos agudos `´`, circunflexos `^`, graves `` ` ``, tis `~`) e o caractere histórico **Cedilha (`ç`)**.

No padrão tradicional ABNT2 (criado para máquinas de escrever brasileiras em meados do século XX):
* O `Ç` recebeu uma tecla física dedicada na mão direita, ao lado do `L`.
* Isso forçou a expulsão das aspas e de sinais de pontuação para locais periféricos.

Nos teclados compactos ergonômicos mundiais (onde a contagem de teclas é intencionalmente reduzida para manter tudo ao alcance da mão), reservar uma tecla inteira exclusivamente para o `Ç` quebra a simetria de símbolos internacionais essenciais para o desenvolvimento de software.

A comunidade técnica brasileira adotou com estrondoso sucesso o padrão **US-International (US-Intl) com teclas mortas (*dead keys*)**.

### 6.3 Métricas de eficiência: Same-Finger Bigrams e Hand Alternation
Na linguística computacional de layouts, duas métricas determinam a velocidade máxima teórica e o índice de conforto articular de um digitador:

1. **Same-Finger Bigrams (SFB)**: Ocorre quando duas letras consecutivas de uma palavra precisam ser pressionadas sucessivamente pelo **mesmo dedo em teclas diferentes** (por exemplo, no QWERTY, digitar `ED` força o dedo médio a esticar para cima e depois dobrar para o meio, ou `CE` forçando o dedo médio a dobrar para baixo e pular para cima). O SFB é o maior destruidor de fluidez motora: a velocidade cai pela metade porque o músculo agonista e antagonista do mesmo dedo precisa frear, reposicionar e reacelerar o membro.
2. **Alternância entre Mãos (*Hand Alternation*)**: Ocorre quando a primeira letra é batida pela mão direita e a segunda pela mão esquerda. O ser humano é capaz de realizar alternâncias de mão a velocidades sobre-humanas (mais de 120 a 160 palavras por minuto) porque a mão secundária se move de forma concorrente em antecipação motora (*motor pre-planning*).

### 6.4 A questão do Cedilha (`ç`): Por que o Tap-Dance no C falha na programação
Um questionamento recorrente de desenvolvedores que chegam aos teclados split é:  
*"Por que não configurar um Tap-Dance no firmware, de modo que apertar 'c' uma vez digite 'c', e apertar 'c' duas vezes rápido dispare o 'ç'?"*

A resposta reside na análise cruzada do léxico da programação contemporânea e da língua inglesa:

#### A Armadilha dos Bigramas Duplos (`cc`)
Em código de software moderno (JavaScript, TypeScript, Python, C, CSS, Go, Rust), o bigrama `cc` é absurdamente frequente em palavras-chave e nomes de variáveis fundamentais:
```text
  access, accessible, accept, accepted, account, 
  success, successful, succeed, accurate, accrue, 
  accelerate, accumulate, occupy, occur, occurrence,
  classes CSS: .account-balance, .success-message
```
Se o firmware estiver configurado com Tap-Dance para transformar duplo clique no `C` em `ç`:
1. Quando o programador digitar `success`, a controladora interceptará os dois `c` seguidos e produzirá: `suçess`.
2. Ao digitar `access`, o resultado será: `açept`.
3. Além disso, o Tap-Dance força o microcontrolador a reter a primeira tecla em um buffer temporário pelo período de tempo definido pelo *Tapping Term* (geralmente entre 150ms e 200ms) para aguardar o possível segundo clique. Isso gera um atraso perceptível na tela (*input lag*) para quem digita com velocidade e fluidez.

#### A Superioridade do US-Intl com Dead Key na Home Row
No layout do Silakka54 configurado para US-Intl:
* A tecla de aspas/apóstrofo (`KC_QUOT`) fica na **Home Row da mão direita** (ao lado do ponto e vírgula).
* Para digitar `ç`, o usuário aperta **`'` (aspas/apóstrofo na mão direita)** e imediatamente aperta **`c` (na mão esquerda)**.
* **Benefício Biomecânico**: Ocorre a mais pura **Alternância de Mãos (*Hand Alternation*)**. Não há qualquer latência no firmware, não há conflito com código em inglês e a memória muscular permanece 100% idêntica aos teclados tradicionais de alta qualidade (como o AULA F75 e teclados padrão ANSI).
* Como alternativa instantânea de um único acorde motor, o usuário pode pressionar **`AltGr + ,` (Polegar Direito + Vírgula)** para cuspir o `ç` em uma fração de segundo.

### 6.5 Topologia de operadores para desenvolvedores
O código-fonte de qualquer linguagem moderna difere radicalmente da prosa literária pelo uso intensivo de símbolos matemáticos e delimitadores de escopo:
* Delimitadores pareados: `( )`, `{ }`, `[ ]`, `< >`
* Operadores de atribuição e lógica: `=`, `==`, `===`, `=>`, `!=`, `&&`, `||`
* Operadores matemáticos e de caminho: `+`, `-`, `*`, `/`, `\`, `_`

No teclado comum, esses símbolos estão espalhados aleatoriamente pela linha superior de números e pelas bordas extremas do teclado, exigindo contorções acrobáticas do dedo mindinho combinadas com a tecla `Shift`.

No Silakka54, a topologia de sintaxe foi organizada na **Layer 2 (Camada de Símbolos)** por **afinidade geométrica e semântica**:
* Os pares de delimitadores foram colocados **lado a lado nos mesmos dedos**:
  * Indicador e médio esquerdo: `(` e `)`
  * Médio e anelar esquerdo: `{` e `}`
  * Linha inferior: `[` e `]`, seguidos de `<` e `>`
* Os operadores de cálculo e lógica foram centralizados na **Home Row da mão direita**:
  * Dedo indicador: `=` (o operador de atribuição mais digitado na programação)
  * Dedo médio: `+`
  * Dedo anelar: `-`
  * Dedo mindinho: `*`
  * Tecla adjacente: `/`

O desenvolvedor pode escrever equações e blocos de código inteiros sem jamais retirar os dedos da postura sagrada de repouso.

---

# Capítulo 7: A Filosofia das Camadas Virtuais e a Simbiose com Linux/Vim

### 7.1 O paradoxo de volume: Como 54 teclas realizam mais que 104
À primeira vista, o observador leigo que olha para um Silakka54 de 54 teclas assume que o dispositivo "perdeu teclas" e, portanto, é inferior a um teclado completo de 104 teclas.

Essa premissa ignora o princípio fundamental da **abstração dimensional por camadas**. Um teclado de 104 teclas é uma interface puramente bidimensional estática ($X, Y$). Para alcançar uma tecla, a mão física do operador precisa se deslocar através da mesa.

Um teclado ergonômico programável opera em três dimensões ($X, Y, Z$), onde o eixo $Z$ representa o **tempo e o estado lógico do firmware** através de camadas virtuais (*layers*).

```text
CONCEITO DE CAMADAS NO FIRMWARE (Eixo Z):
   [ Layer 4: Modo Mouse Vim (HJKL = Ponteiro, Web Nav) ]
      [ Layer 3: Numpad / Calculadora Física & Teclas F1-F12 ]
         [ Layer 2: SYM - Símbolos de Programação & Operadores ]
            [ Layer 1: NAV - Setas Vim, Home, End, PageUp/Dn & Mídia ]
               [ Layer 0: BASE - Digitação QWERTY US-Intl + DWM Modifiers ]
```

Ao manter todas as 54 teclas sob o alcance direto das falanges sem necessidade de movimentação dos braços, o operador tem acesso instantâneo a centenas de combinações funcionais, códigos de escape e comandos do sistema operacional com esforço físico nulo.

### 7.2 Mecânica de transição de camadas: MO, TG e TO
O firmware QMK/Vial implementa três primitivas de máquina de estados para comutação de camadas:
1. **`MO(layer)` (Momentary Switch)**:
   A camada de destino permanece ativa estritamente enquanto a tecla ativadora estiver sendo pressionada pelo usuário. Ao soltar a tecla, o teclado reverte instantaneamente para a camada base. Utilizado no Silakka54 nos polegares para as camadas de Navegação (`MO(1)`) e Símbolos (`MO(2)`).
2. **`TG(layer)` (Toggle Switch)**:
   A tecla funciona como um interruptor liga/desliga de lâmpada. Um toque no acorde ativa e trava o teclado na camada desejada; outro toque desliga e destrava.
3. **`TO(layer)` (Direct Jump Switch)**:
   Desativa todas as outras camadas ativas e transporta o teclado incondicionalmente para a camada especificada. Utilizado na Layer 4 do Silakka54 nas teclas `Esc`, `Caps`, `B` e no centro dos polegares para retornar instantaneamente à digitação na Layer 0.

### 7.3 Arquitetura de modais no Vim e Gerenciadores de Janela em Mosaico (DWM)
A mentalidade que rege o editor de texto **Vim / Neovim** e o gerenciador de janelas **DWM (Dynamic Window Manager)** é estritamente isomorfa à mentalidade do teclado ergonômico programável:
* No Vim, você não digita teclas de controle contorcendo as mãos: você alterna entre o **Modo Normal**, **Modo de Inserção** e **Modo Visual**.
* No DWM, o ambiente gráfico dispensa barras de rolagem e cliques dispersos em ícones: janelas se dividem em algoritmos de mosaico (*master-and-stack*) orquestrados pelo modificador mestre **Mod4 (Super / Windows)**.

A arquitetura do Silakka54 foi desenhada especificamente para essa tríade (Linux + DWM + Vim):
* **O modificador Super / Mod4 no Polegar Esquerdo**:
  No teclado convencional, usar `Super + Enter` para abrir um terminal `st` ou `Super + J / K` para alternar janelas no DWM exige dobrar o mindinho esquerdo para baixo ou fazer malabarismos. No Silakka54, o **Super repousa sob o polegar esquerdo**. O polegar apenas pressiona levemente para baixo enquanto os outros dedos comandam as janelas sem esforço.
* **CapsLock de Função Dupla (*Dual-Role / Mod-Tap*)**:
  A tecla física do CapsLock foi configurada com a instrução de firmware `LCTL_T(KC_ESC)`:
  * **Toque rápido (*Tap*)**: Envia o sinal de `Escape`, essencial para retornar instantaneamente ao Modo Normal no Vim.
  * **Pressionar contínuo (*Hold*)**: Funciona como o `Control (Ctrl)` padrão para atalhos de terminal Unix (`Ctrl+C`, `Ctrl+Z`, `Ctrl+R`, `Ctrl+W`).
  O CapsLock tradicional (uma das teclas mais nobres e acessíveis do teclado, historicamente desperdiçada em gritar maiúsculas) transforma-se na ferramenta de controle mais poderosa da mão esquerda.

---

# Capítulo 8: Especificações Técnicas de Engenharia do Silakka54

### 8.1 Arquitetura do microcontrolador RP2040
O coração eletrônico do Silakka54 é o microcontrolador **RP2040**, desenvolvido pela *Raspberry Pi Foundation*:
* **Núcleo**: Dual-core ARM Cortex-M0+ operando a uma frequência flexível de até **133 MHz** (contra os modestos 16 MHz do antigo ATmega32U4 de 8 bits dos anos 2010).
* **Memória**: 264 KB de SRAM interna de alta velocidade, dividida em seis bancos independentes.
* **Barramento I/O Programável (PIO)**: Máquinas de estado de hardware dedicadas que descarregam as rotinas de escaneamento de matriz e comunicação USB dos núcleos principais.
* **Conectividade**: Interface USB 2.0 nativa operando com *polling rate* estável de **1000 Hz** (1 milissegundo de tempo de resposta).

### 8.2 Matriz de escaneamento, diodos anti-ghosting e NKRO
O circuito do Silakka54 é estruturado em uma matriz elétrica de linhas e colunas. Cada switch mecânico é associado em série com um **diodo de comutação rápida 1N4148** (ou equivalente de montagem em superfície SMD SOD-123).

A presença do diodo individual para cada chave isola a corrente elétrica e impede o fenômeno de fuga parasita conhecido como *Ghosting* ou *Masking* (quando o fechamento simultâneo de três teclas em um retângulo elétrico faz a controladora registrar falsamente uma quarta tecla fantasma). O Silakka54 opera em regime de **Full N-Key Rollover (NKRO)**: todas as 54 teclas podem ser pressionadas simultaneamente pelo usuário e serão reconhecidas pelo kernel Linux sem perda de sinal.

### 8.3 O protocolo Vial e a EEPROM virtual
O firmware do Silakka54 implementa o protocolo aberto **Vial (Protocolo 6)**:
* A memória Flash do RP2040 emula um bloco de memória EEPROM não-volátil.
* A controladora expõe um endpoint USB HID dedicado para transmissão de pacotes de dados brutos (*Raw HID*).
* Quando o usuário conecta o teclado e abre a aplicação do Vial, o software consulta a definição física da geometria do teclado e lê os ponteiros de camadas armazenados em memória.
* Ao remapear qualquer tecla, o Vial grava os novos keycodes diretamente na Flash via comandos seguros em tempo real. O teclado é reconfigurado **instantaneamente em nível de hardware**, sem depender de nenhum software instalado em segundo plano no sistema operacional.

---

### 8.4 Mapeamento Completo das Camadas do Silakka54

Abaixo está o mapa técnico detalhado das 5 camadas ativas implementadas no arquivo de produção `silakka54-fabio-vim-dwm.vil`:

#### Layer 0: BASE (QWERTY US-Intl Otimizado para DWM & Vim)
```text
[METADE ESQUERDA]
Linha 0:  ` / ~    1      2      3      4      5
Linha 1:  TAB      Q      W      E      R      T
Linha 2:  ESC/CTL  A      S      D      F      G
Linha 3:  SHIFT    Z      X      C      V      B
Polegar:  SUPER    MO(1)  ESPAÇO

[METADE DIREITA]
Linha 0:  6        7      8      9      0      - / _
Linha 1:  Y        U      I      O      P      BACKSPACE
Linha 2:  H        J      K      L      ; / :  ' / "  (Acentos & Ç!)
Linha 3:  N        M      , / <  . / >  / / ?  SHIFT
Polegar:  ENTER    MO(2)  ALT_GR
```

#### Layer 1: NAVEGAÇÃO, DWM & MULTIMÍDIA (Ativada segurando o Polegar Esquerdo: `MO(1)`)
```text
[METADE ESQUERDA]
Linha 0:  ___      PREV   NEXT   PLAY   VOL-   VOL+
Linha 1:  ___      MUTE   BRI+   PRTSCR ___    ___
Linha 2:  ___      BRI-   ALT    SHIFT  CTRL   SUPER
Linha 3:  ___      ___    ___    ___    TG(4)  TG(4) (Atalhos do Modo Mouse!)
Polegar:  SUPER    ___    MO(3)

[METADE DIREITA]
Linha 0:  ___      ___    ___    ___    ___    ___
Linha 1:  ___      HOME   PGUP   PGDN   END    DEL
Linha 2:  LEFT(H)  DOWN(J)UP(K)  RGHT(L)INS    ___    (Navegação pura do Vim!)
Linha 3:  ___      BSPC   DEL    ___    ___    ___
Polegar:  ENTER    MO(3)  ___
```

#### Layer 2: SÍMBOLOS DE PROGRAMAÇÃO (Ativada segurando o Polegar Direito: `MO(2)`)
```text
[METADE ESQUERDA]
Linha 0:  ~        !      @      #      $      %
Linha 1:  ___      (      )      {      }      |      (Delimitadores em Pares!)
Linha 2:  ___      &      *      -      +      =      (Operadores na mão esquerda)
Linha 3:  ___      [      ]      <      >      \
Polegar:  SUPER    MO(3)  ESPAÇO

[METADE DIREITA]
Linha 0:  ^        &      *      (      )      +
Linha 1:  !        :      ?      "      '      BSPC
Linha 2:  =        +      -      *      /      :      (Operadores na Home Row direita!)
Linha 3:  _        %      ;      .      /      ___
Polegar:  ENTER    ___    ALT_GR
```

#### Layer 3: CALCULADORA FÍSICA & TECLAS F1-F12 (Segurar Ambos os Polegares: `MO(3)`)
```text
[METADE ESQUERDA]
Linha 0:  ___      F1     F2     F3     F4     F5
Linha 1:  ___      F6     F7     F8     F9     F10
Linha 2:  ___      F11    F12    ___    ___    ___
Linha 3:  ___      ___    ___    ___    ___    ⚡ BOOTLOADER (Flash RP2040)
Polegar:  ___      ___    ___

[METADE DIREITA]
Linha 0:  ___      7      8      9      *      ___
Linha 1:  ___      4      5      6      +      ___
Linha 2:  ___      1      2      3      -      NUM_ENTER
Linha 3:  0        0      .      /      =      ___
Polegar:  NUM_ENTER ___   ___
```

#### Layer 4: MODO MOUSE VIM & NAVEGAÇÃO WEB (`TG(4)`: Polegar E + `V` ou `B`)
```text
[METADE ESQUERDA - Comandos & Cliques]
Linha 0:  SAIR(0)  SNIPER(1) NORMAL(2) TURBO(3)  ___       ___
Linha 1:  TAB      ___       SCR_CIMA  SCR_BAIXO ___       ___
Linha 2:  SAIR(0)  SNIPER(A) BTN_MEIO  BTN_ESQ   BTN_DIR   BTN_ESQ
Linha 3:  SHIFT    VOLTAR(Z) AVAN(X)   F_ABA(C)  N_ABA(V)  SAIR(B)
Polegar:  BTN_ESQ  SAIR(0)   BTN_DIR

[METADE DIREITA - Cursor & Rolagem]
Linha 0:  ___      ___       ___       ___       ___       ___
Linha 1:  SCR_ESQ  SCR_CIMA  SCR_BAIXO SCR_BAIXO SCR_DIR   BSPC
Linha 2:  MS_ESQ(H)MS_BAIX(J)MS_CIMA(K)MS_DIR(L) BTN_ESQ   BTN_DIR
Linha 3:  BTN_ESQ  BTN_DIR   BTN_MEIO  VOLTAR(.) AVAN(/)   SAIR(0)
Polegar:  BTN_ESQ  SAIR(0)   BTN_DIR
```

---

# Capítulo 9: Neurobiologia da Memória Motora e Protocolos de Treinamento

### 9.1 Gânglios da base, cerebelo e a mielinização dos circuitos
A aquisição da habilidade de digitação rápida e inconsciente (*muscle memory*) não é um processo muscular periférico, mas sim uma reorganização sináptica profunda do sistema nervoso central:
1. **Fase Cognitiva (Córtex Pré-Frontal)**: O digitador iniciante precisa pensar conscientemente sobre cada movimento. O cérebro localiza a tecla no mapa mental e dispara uma ordem motora voluntária lenta.
2. **Fase Associativa (Cerebelo e Córtex Motor)**: O cerebelo começa a corrigir os erros espaciais através de feedback sensorial e cinestésico. Começam a se formar padrões de agrupamento motor (*motor chunking*).
3. **Fase Autônoma (Gânglios da Base - Putâmen e Globo Pálido)**: O gesto motor é totalmente automatizado em sub-rotinas neuromusculares inconscientes. Os axônios dos circuitos envolvidos sofrem intensa **mielinização** (acúmulo de bainha de mielina), permitindo que os potenciais de ação viajem a velocidades de até 120 metros por segundo. O desenvolvedor apenas visualiza a palavra ou o operador mentalmente e seus dedos disparam a sequência sem mediação voluntária.

### 9.2 Superando o Vale da Desilusão na transição para o layout colunar
Ao migrar de um teclado tradicional em degraus (*row-stagger*) para o alinhamento colunar ergonômico do Silakka54, o cérebro humano experimenta o fenômeno neurofisiológico conhecido como **Inibição Pró-Ativa**:
* Os circuitos neurais consolidados por anos de digitação torta tentam forçar o dedo indicador e médio a realizarem o desvio lateral involuntário.
* A velocidade de digitação temporariamente despenca nas primeiras 72 horas de uso, caindo de 70-80 WPM para 25-35 WPM.
* **O "Vale da Desilusão"**: É o ponto crítico em que muitos usuários desistem e voltam para o teclado velho. Compreender que essa queda temporária é um processo estritamente biológico de poda sináptica e recriação de mapas no córtex motor primário é fundamental para perseverar. Entre o quarto e o sétimo dia de uso dedicado, a curva de aprendizado experimenta uma inflexão exponencial e a velocidade é totalmente recuperada com conforto infinitamente superior.

```text
A CURVA DE TRANSIÇÃO DO LAYOUT:
  Velocidade
      ^
      | [Velocidade Antiga no Teclado Torto]
      |   \                                 /-- [Novo Nível Ergonômico Superior]
      |    \                               /
      |     \-- [O Vale da Desilusão] ----/
      |           (Adaptação Neural: 3 a 7 dias)
      +----------------------------------------------------> Tempo
```

### 9.3 Métodos de treino deliberado para o desenvolvedor
Para consolidar os circuitos motores do Silakka54 sem sofrimento, recomenda-se a seguinte rotina diária de 20 minutos de **Treinamento Deliberado**:

1. **Protocolo de Acurácia Máxima (Monkeytype / Keybr)**:
   * Dedique 10 minutos por dia na plataforma [keybr.com](https://www.keybr.com) ou [monkeytype.com](https://monkeytype.com).
   * **Regra Sagrada**: Ignore completamente a velocidade (WPM). Foque obsessivamente em manter uma taxa de precisão (*Accuracy*) acima de **98%**. A velocidade é uma consequência natural da precisão motora; a velocidade forçada sobre erros apenas reforça trajetórias neurais defeituosas.
2. **Treino de Acentuação e Símbolos em Português**:
   * Pratique a digitação cadenciada de palavras frequentes com acento agudo e cedilha no padrão US-Intl:
     * `' + c` ➔ `coração`, `ação`, `espaço`, `definição`, `começo`.
     * `' + vogal` ➔ `código`, `fácil`, `usuário`, `técnica`, `função`.
     * `~ + a/o` ➔ `não`, `mão`, `visão`, `padrão`, `informação`.
3. **Treino de Sintaxe de Código e Operadores da Layer 2**:
   * Escreva estruturas sintáticas reais de programação para consolidar os operadores da Home Row:
     ```javascript
     const calculateTotal = (items) => {
       return items.reduce((acc, curr) => acc + curr.price, 0);
     };
     ```
   * Sinta a facilidade de acionar parênteses `( )`, chaves `{ }`, setas `=>`, igualdade `=` e adição `+` usando apenas o polegar direito e os dedos na posição de descanso.

---

# Capítulo 10: Glossário e Referências Bibliográficas Científicas
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

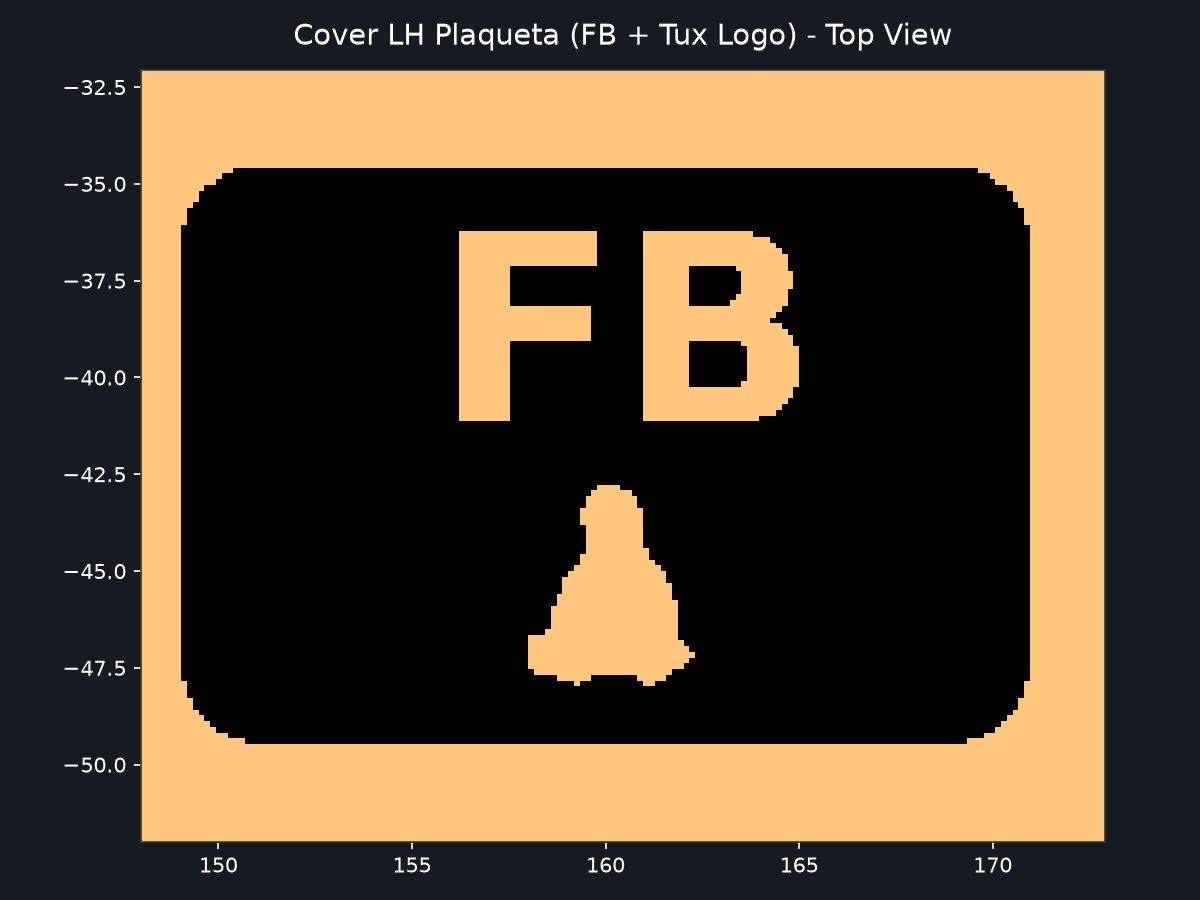
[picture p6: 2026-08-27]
docs/01-final/previews/preview-cover-plaque-LH.png

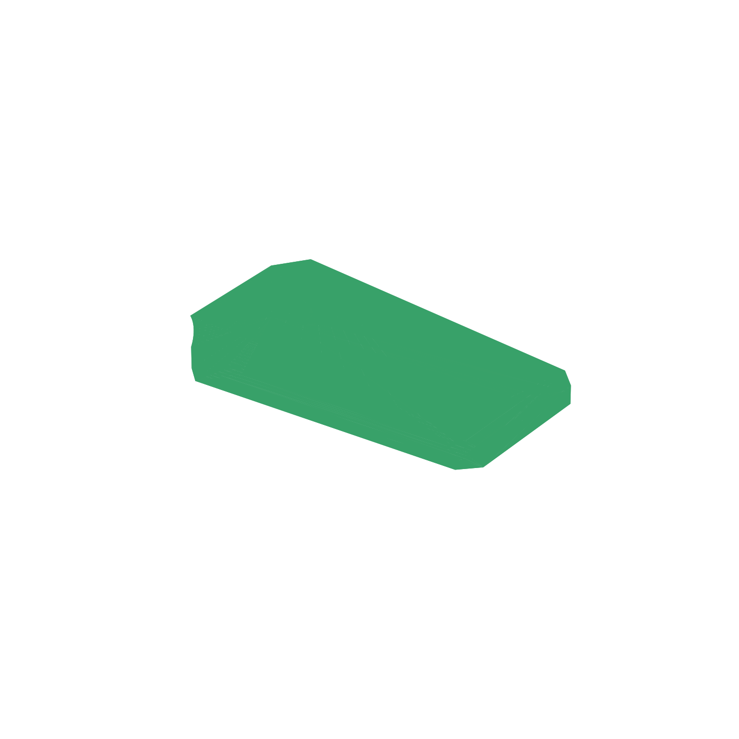
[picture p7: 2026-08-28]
docs/01-final/previews/preview-palm-rest-RH.png

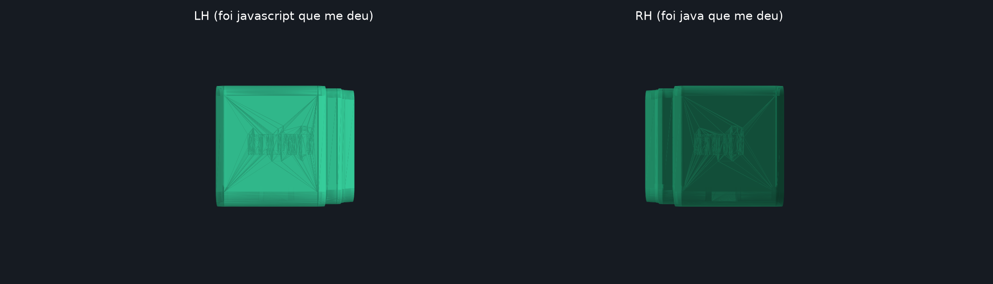
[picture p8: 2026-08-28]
docs/01-final/previews/preview-slim-side-check.png

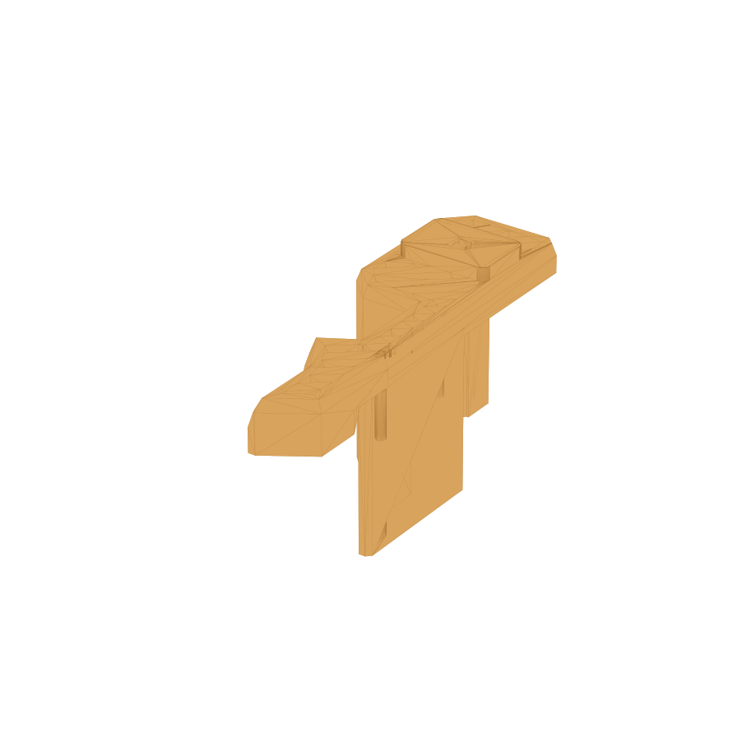
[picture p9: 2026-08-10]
docs/01-final/previews/preview-B-linux-RH.png

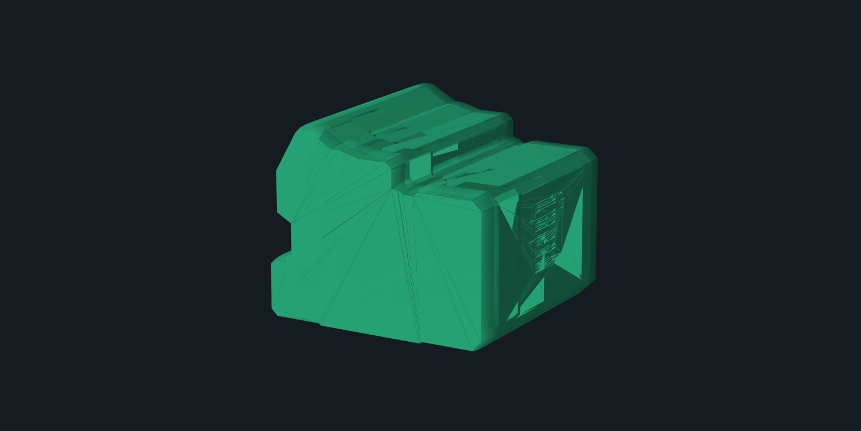
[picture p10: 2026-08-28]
docs/01-final/previews/preview-slim-side-RH.png

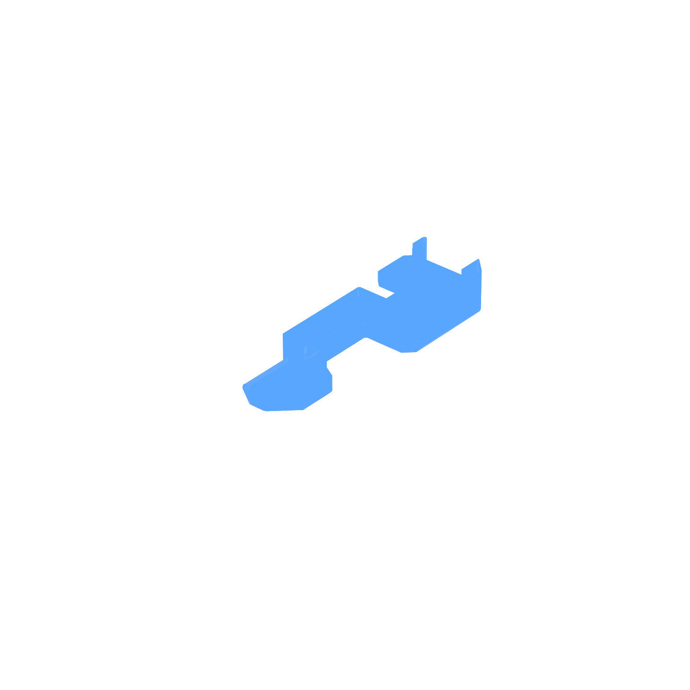
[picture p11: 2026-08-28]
docs/01-final/previews/preview-slim-cover-B-linux-RH.png

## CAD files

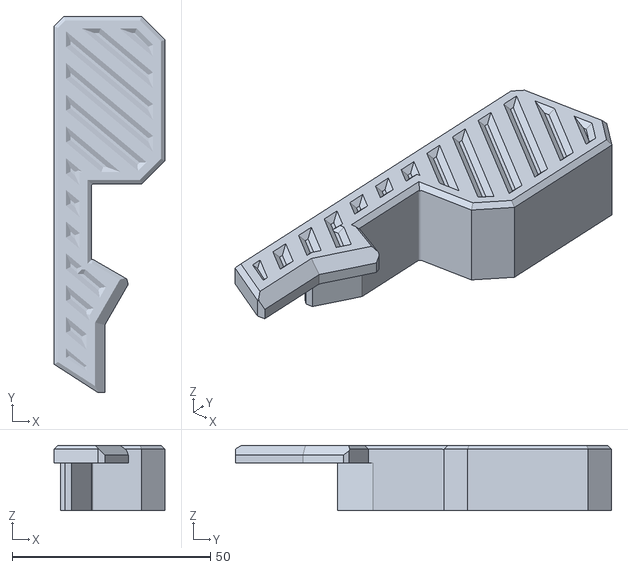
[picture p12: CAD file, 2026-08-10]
00-original/case-keyboard/full-mcu-cover-chevrons.stl
28.0 x 94.8 x 16.5

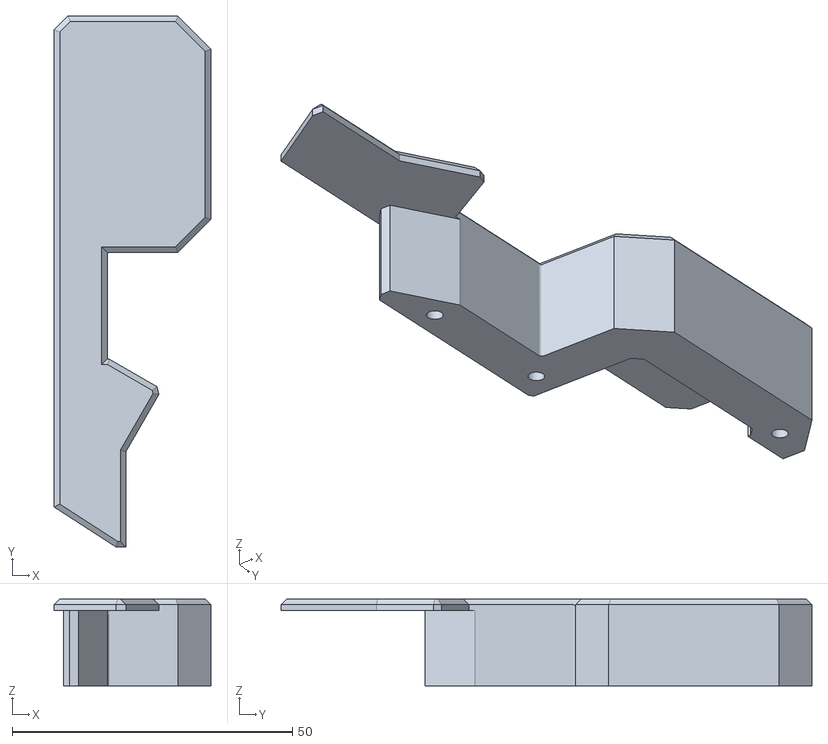
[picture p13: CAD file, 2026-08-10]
00-original/case-keyboard/full-mcu-cover.stl
28.0 x 94.8 x 15.5

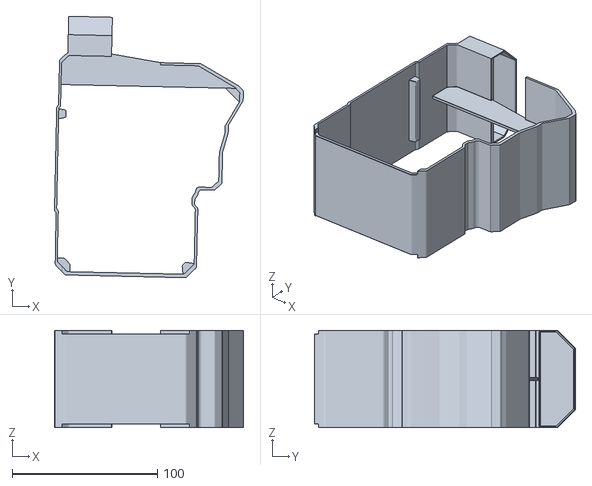
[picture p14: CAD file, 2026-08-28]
01-final/carry-tent-2em1/silakka-case-67mm.stl
130.1 x 179.9 x 67.0

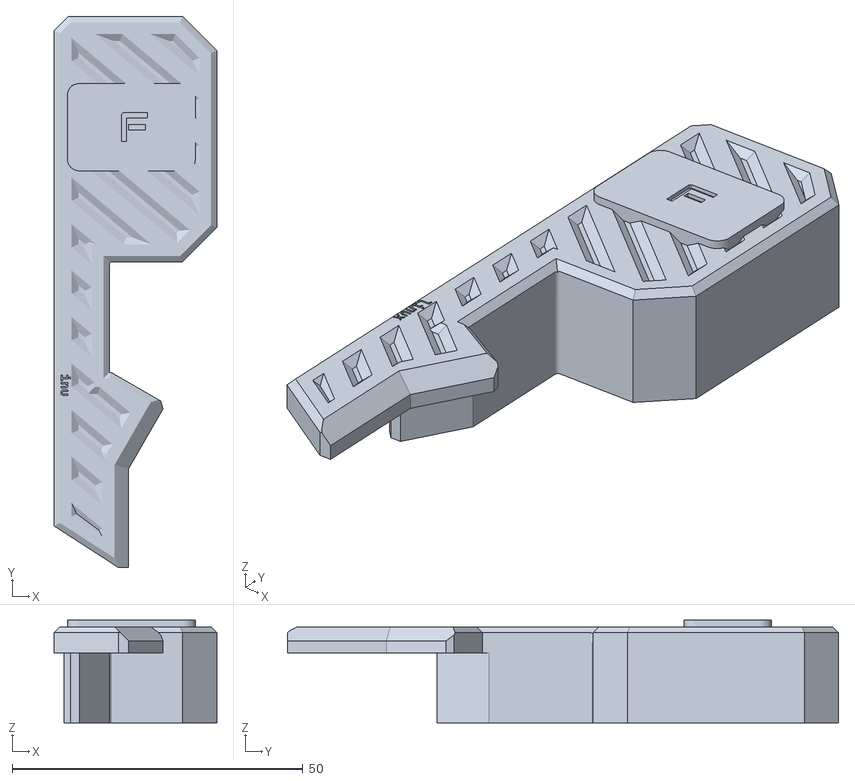
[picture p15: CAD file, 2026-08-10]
01-final/LH/silakka54-chevron-cover-F-linux-LH.stl
28.0 x 94.8 x 17.7

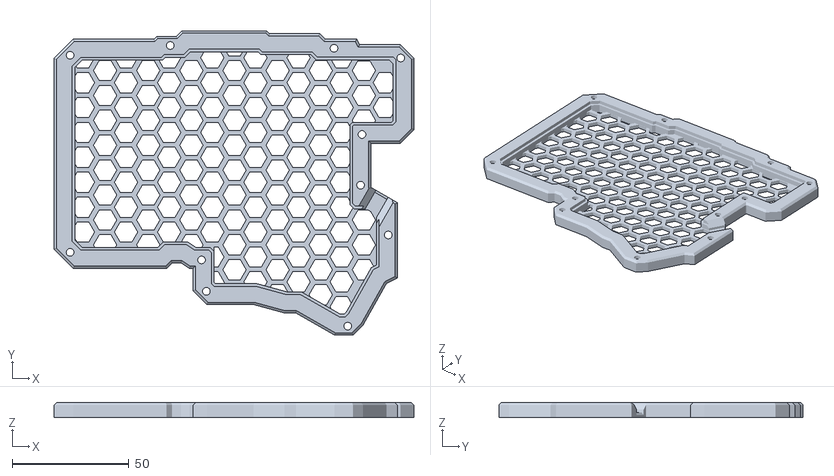
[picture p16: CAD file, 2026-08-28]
docs/01-final/LH/silakka54-baseplate-js-LH.stl
154.1 x 130.3 x 6.25

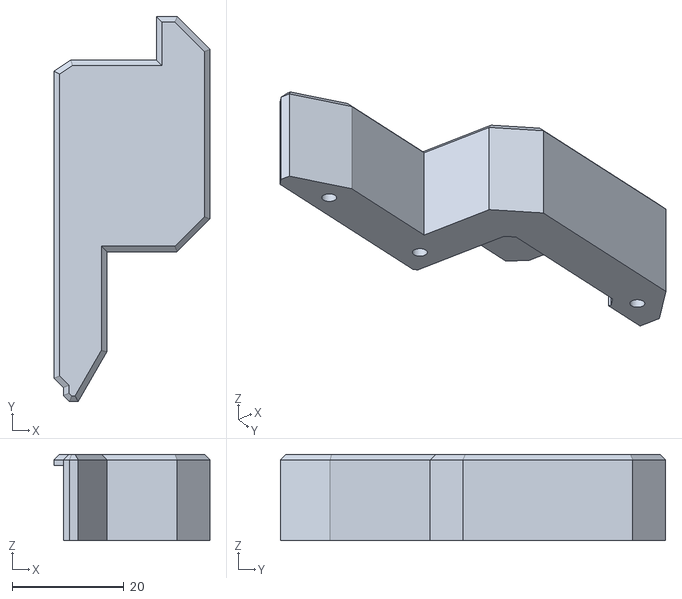
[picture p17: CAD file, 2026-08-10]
00-original/case-keyboard/50pct-mcu-cover.stl
28.0 x 69.0 x 15.5

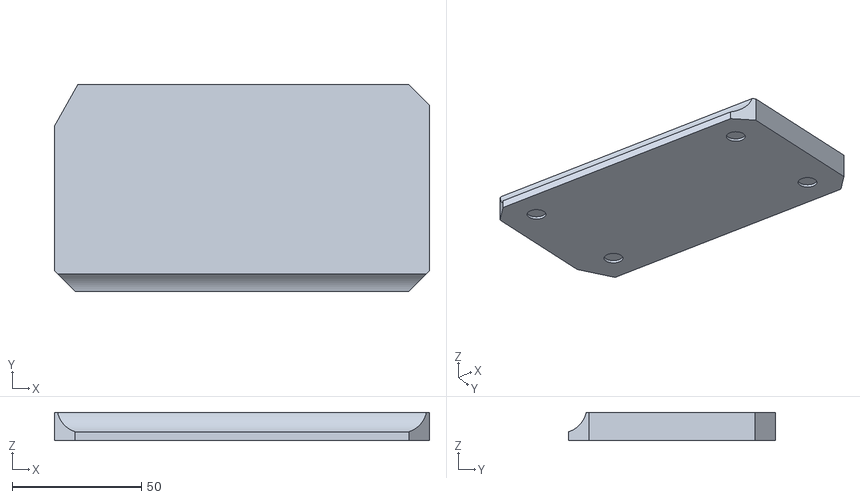
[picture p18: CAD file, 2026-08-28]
docs/01-final/carry-tent-2em1/silakka54-flat-palm-rest-RH.stl
145.0 x 80.0 x 11.0

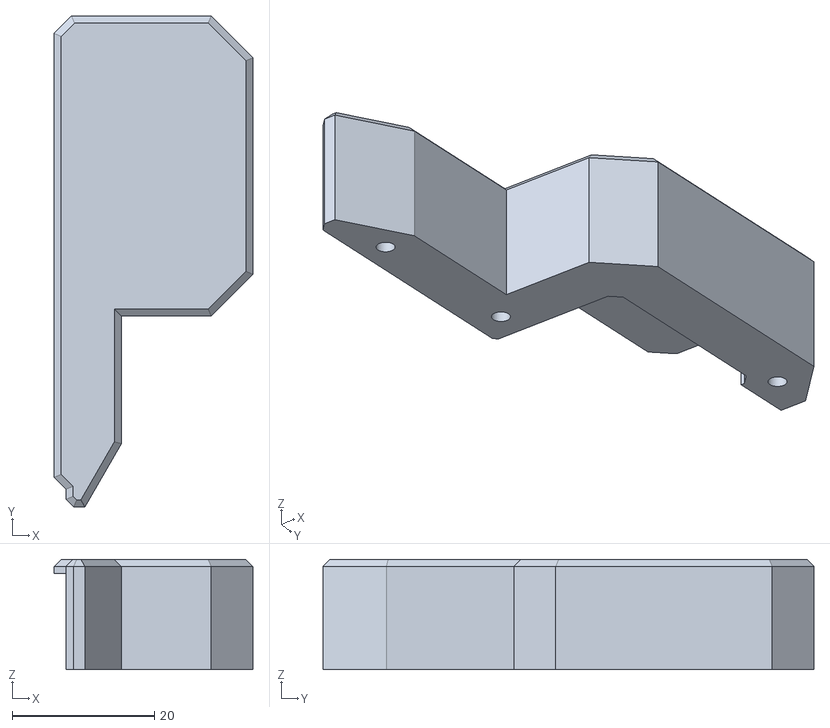
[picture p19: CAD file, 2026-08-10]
00-original/case-keyboard/75pct-mcu-cover.stl
28.0 x 69.0 x 15.5

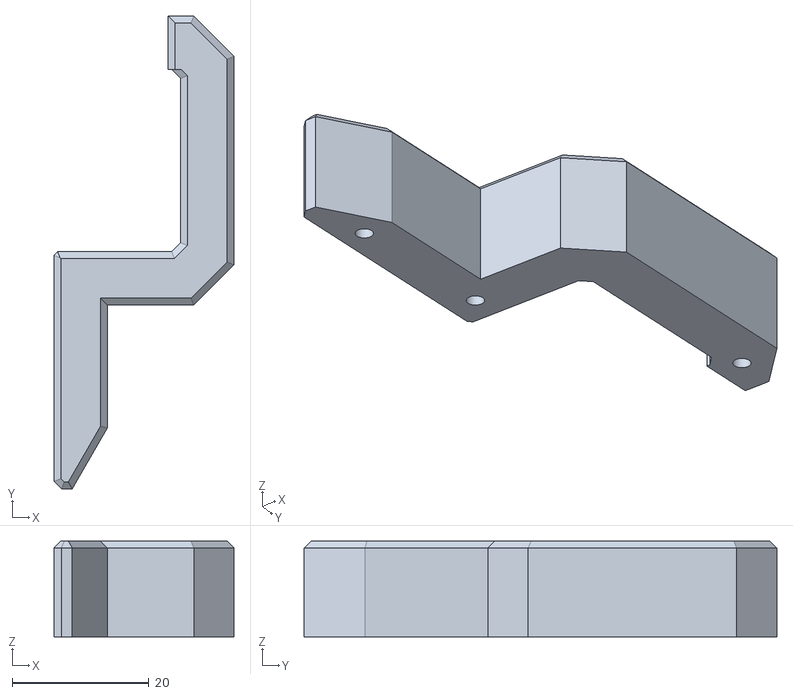
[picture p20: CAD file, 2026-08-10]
00-original/case-keyboard/no-cover-top-frame.stl
26.3 x 69.0 x 14.0

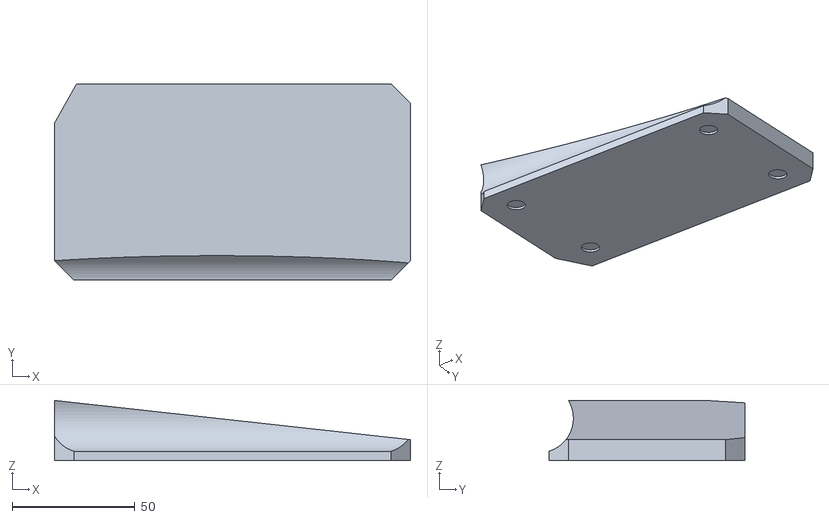
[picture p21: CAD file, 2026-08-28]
docs/01-final/carry-tent-2em1/silakka54-tented-palm-rest-RH.stl
145.0 x 80.0 x 24.5

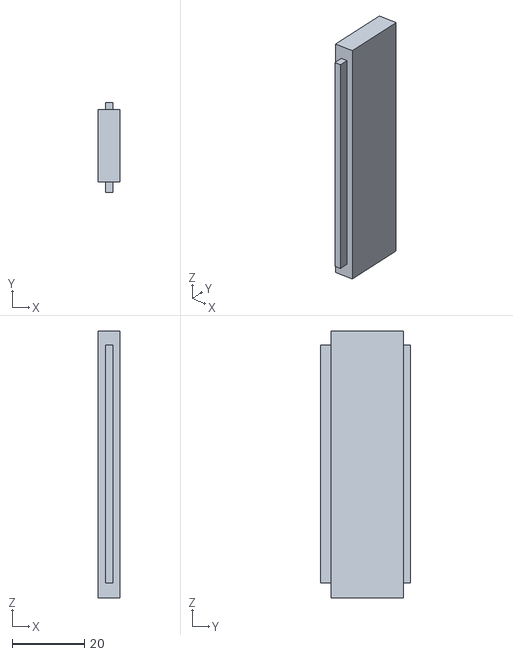
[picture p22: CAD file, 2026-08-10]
docs/01-final/carry-tent-2em1/silakka54_tilt_wedge_xdeg.stl
6.00 x 25.0 x 74.0

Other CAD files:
01-final/RH/silakka54-chevron-cover-B-linux-RH.stl
docs/01-final/RH/silakka54-baseplate-java-RH.stl
docs/01-final/LH/silakka54-chevron-cover-FB-Tux-linux-LH.stl
docs/01-final/RH/silakka54-chevron-cover-FB-Tux-linux-RH.stl
docs/01-final/carry-tent-2em1/silakka54-flat-palm-rest-LH.stl
docs/01-final/carry-tent-2em1/silakka54-tented-palm-rest-LH.stl
00-original/case-keyboard/silakka54-baseplate-screwunderneath.stl
02-superseded/silakka54-chevron-cover-B-linux-RH.stl
02-superseded/silakka54-chevron-cover-B-vim-RH.stl
02-superseded/silakka54-chevron-cover-F-LH.stl
02-superseded/silakka54-chevron-cover-FB-Tux-LH.stl
02-superseded/silakka54-chevron-cover-FB-Tux-RH.stl
docs/01-final/carry-tent-2em1/silakka54-case.stl
docs/01-final/carry-tent-2em1/silakka54_left_base_support.stl
docs/01-final/carry-tent-2em1/silakka54_left_side_shell.stl
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

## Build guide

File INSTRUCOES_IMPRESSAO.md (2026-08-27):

# Instruções de Impressão — Silakka54 personalizado (v3.0 Fabio: FB + Tux + linux + Kit 2-em-1)

Guia para a pessoa/gráfica que vai imprimir. Teclado **split** = 2 metades (L = left,
R = right). Total: **4 peças customizadas + 2 top frames + Kit 2-em-1 Carry Case & Tent**.

---

## Lista de impressão principal (teclado)

| # | Arquivo | Qtd | Lado | Observação |
|---|---|---|---|---|
| 1 | `01-final/LH/silakka54-baseplate-js-LH.stl` | 1 | Esquerdo | Imprimir **direto** (frase "Foi o JavaScript..." por baixo — orientação corrigida) |
| 2 | `01-final/RH/silakka54-baseplate-java-RH.stl` | 1 | Direito | Imprimir **direto** — JÁ vem espelhado (frase "Foi o Java..." por baixo — orientação corrigida) |
| 3 | `01-final/comum/silakka54-top-frame-screwunderneath.stl` | 2 | 1 esq. + 1 dir. | **Espelhar em X APENAS uma cópia** (a do lado direito) no fatiador |
| 4 | `01-final/LH/silakka54-chevron-cover-FB-Tux-linux-LH.stl` | 1 | Esquerdo | Imprimir **direto** ("FB" + Logo Tux Linux + "linux" na lateral) |
| 5 | `01-final/RH/silakka54-chevron-cover-FB-Tux-linux-RH.stl` | 1 | Direito | Imprimir **direto** — JÁ vem espelhado ("FB" + Tux + "linux" na lateral) |

> ⚠️ **NUNCA espelhar os arquivos RH** (`*java-RH.stl`, `*RH.stl`): eles já saíram
> espelhados do modelo, com o texto e logos re-gravados legíveis. Espelhamento duplo = texto invertido.

## Kit 2-em-1 (Carry Case + Tenting Platform)

| Arquivo | Papel |
|---|---|
| `01-final/carry-tent-2em1/silakka-case-67mm.stl` | Estojo de transporte que acomoda o teclado montado com a plataforma de tenting |
| `01-final/carry-tent-2em1/silakka54-case.stl` | Variante padrão do carry case |
| `01-final/carry-tent-2em1/silakka54_left_side_shell.stl` / `silakka54_right_side_shell.stl` | Shells laterais de apoio ergonômico |
| `01-final/carry-tent-2em1/silakka54_left_base_support.stl` / `silakka54_right_base_support.stl` | Suportes de base com elevação/tenting |
| `01-final/carry-tent-2em1/silakka54_tilt_wedge_xdeg.stl` | Cunha de inclinação (tilt wedge) |
| `00-original/case-keyboard/full-mcu-cover.stl` ou `75pct-mcu-cover.stl` / `50pct-mcu-cover.stl` | Covers alternativos (liso / parciais) caso não queira o chevron |
| `00-original/case-keyboard/no-cover-top-frame.stl` | Top frame sem recorte de cover |

## Parâmetros sugeridos

- **Material**: PLA ou PETG (PETG recomendado para durabilidade nas bordas de encaixe dos
  switches; PLA bem calibrado também funciona — folgas do projeto original).
- **Bico / camada**: bico 0,4 mm · camada 0,2 mm (relevos de 0,5–0,55 mm resolvem limpo).
- **Suportes**: NÃO usar. Todas as peças imprimem sem suporte.

## Orientação na mesa

- **Covers (chevron)**: plaqueta com a gravação ("F" / "B") **para cima** (face lisa
  de topo no prato). O relevo é gravado (rebaixado) — sem risco de descolar. O "linux"
  fica na lateral (texto vertical, cap 1,7 mm, profundidade 0,55 mm).
- **Baseplates**: face inferior (frase) para baixo, como no STL — a frase fica **visível
  por baixo** do teclado. Imprimir na orientação padrão do arquivo; o recesso de 0,5 mm
  não precisa de suporte.
- **Top frame**: orientação padrão; a cópia do lado direito com espelhamento em X.

## Pós-impressão

- Conferir encaixe dos switches nos 4 cantos de cada metade (folgas do projeto original).
- Montagem: baseplate + top frame (por baixo) + PCB AliExpress compatível (RP2040 /
  QMK-VIAL) + cover chevron na área do MCU. Seguir o PDF do autor em
  `00-original/case-keyboard/1381297-...pdf`.

## Ergonomia (resumo científico — decisão do projeto)

- Case original sai com **0° slope / 0° tenting** — funciona, mas em sessões longas é
  melhor adicionar **tenting 10–15°** + **slope 0° a −4°** (estudos: NIOSH/Chen 2009,
  Rempel 2007). ✅ O kit **"Tent & Tilt Ergonomic Kit"** (Douglas Serrão) **está neste
  pacote**: `00-original/tent-tilt-kit/` (side shells + base supports + tilt wedge).
  Seguir o PDF do kit para impressão/configuração (compatível só com o case screwless).
- Apoio de pulso clássico: **não recomendado** (pressão no túnel do carpo aumenta).
  Prefira apoiar o antebraço e deixar as mãos flutuando/palma em altura das teclas.

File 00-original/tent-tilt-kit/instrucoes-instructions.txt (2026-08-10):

🇧🇷 Instruções (Português):
⚠️ Atenção: Este kit só deve ser impresso se você já tiver impresso o Slim Silakka54 Screwless Case (https://www.printables.com/model/1248872-slim-silakka54-screwless-case).
As peças deste projeto foram desenvolvidas especificamente como complemento para esse case e não são compatíveis com outros modelos.

🇺🇸 Instructions (English):
⚠️ Important: This kit should only be printed if you have already printed the Slim Silakka54 Screwless Case (https://www.printables.com/model/1248872-slim-silakka54-screwless-case).
All parts in this project were designed specifically as add-ons for that case and will not fit other models.

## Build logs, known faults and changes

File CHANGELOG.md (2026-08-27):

# CHANGELOG — Silakka54 (case personalizada)

Histórico completo das modificações: do zip original → versões intermediárias → versão final
("ideal") pronta para mandar imprimir.

Origem: **Silakka54** — teclado split ergonômico (case de Patrick Faulkner, GPL v2.0,
compatível com PCB AliExpress). Remixes de terceiros: "case with less screws" e "Screwless
and Tenting Platform carry case" (Douglas Serrão — remix permitido).

---

## v0 — ORIGINAL (zip, sem modificação)

Fonte: `silakka54-keyboard-case-with-less-screws-aliexpress-pcb-compatible-model_files.zip`
(2025-08-20) → `00-original/case-keyboard/`

| Arquivo | Papel |
|---|---|
| `silakka54-baseplate-screwunderneath.stl` | Baseplate (lado esquerdo — espelhar na fatia p/ direito) |
| `silakka54-top-frame-screwunderneath.stl` | Top frame (lado esquerdo — espelhar na fatia p/ direito) |
| `full-mcu-cover-chevrons.stl` | Cover com padrão chevron (base da nossa personalização) |
| `full-mcu-cover.stl` | Cover liso (alternativa) |
| `50pct-mcu-cover.stl` / `75pct-mcu-cover.stl` | Covers parciais (alternativas) |
| `no-cover-top-frame.stl` | Top frame sem recorte de cover (alternativa) |
| `1381297-...pdf` | Instruções de montagem do autor |

Fonte: `silakka54-screwless-and-tenting-platform-carry-case-model_files.zip`
(2026-03-18) → `00-original/carry-case/`

| Arquivo | Papel |
|---|---|
| `silakka54-case.stl` | Case de transporte (teclado montado + tenting platform) |
| `silakka-case-67mm.stl` | Case de transporte (altura 67 mm) |
| `1433122-...pdf` | Instruções do carry case |

Fonte: `silakka54-tent-tilt-ergonomic-kit-for-slim-screwless-case-model_files.zip`
(2025-05-29) → `00-original/tent-tilt-kit/`

| Arquivo | Papel |
|---|---|
| `silakka54_left_side_shell.stl` / `silakka54_right_side_shell.stl` | Side shells (159×127×7 mm) |
| `silakka54_left_base_support.stl` / `silakka54_right_base_support.stl` | Base supports (157×123×11 mm) |
| `silakka54_tilt_wedge_xdeg.stl` | Cunha de teste p/ angulação (6×25×74 mm) |
| `1312117-...pdf` | Instruções do kit (remix do Slim Screwless Case de Johnny5iv) |

> ⚠️ **Nenhum arquivo de `00-original/` foi alterado.** São a referência intacta.

---

## v1 — INTERMEDIÁRIA (SUPERADA) — cover "FB + Tux"

Pasta de origem: `silakka54-fb-tux/` (cópias em `02-superseded/`)

Modificações sobre `full-mcu-cover-chevrons.stl`:
- Plaqueta integrada 22 × 15 mm (cantos arredondados, +1,15 mm de relevo) no centro da face
  chevron.
- **"FB"** em baixo-relevo 0,55 mm (DejaVu Sans Bold, altura 5 mm) + **logo Tux (Linux)**
  gravado abaixo (silhueta oficial, 5,2 mm), proveniente de `tux.png` (Wikimedia Commons).
- Corpo único watertight, sem flutuação.

**Status: SUBSTITUÍDA** — o usuário pediu o cover redesenhado (v2). Mantida em
`02-superseded/` apenas como histórico (não imprimir).

---

## v2 — FINAL ("ideal") — covers F | B+vim + frases nas baseplates

Pasta de origem: `silakka54-FB-Tux-quote/out/` (cópias em `01-final/`)

### 2.1 `silakka54-chevron-cover-F-LH.stl` — lado ESQUERDO
- Base: `full-mcu-cover-chevrons.stl` (padrão chevron original preservado fora da plaqueta).
- Plaqueta 22 × 15 mm no topo (x 149–171, y −49,5..−34,5), topo z = 23,5. *(Original v1)*.
- Gravação: **"F"** (fonte Audiowide, cap 5 mm), profundidade **0,55 mm** (fundo z = 22,95).
- Imprimir **direto, sem espelhar** (texto já legível).

### 2.2 `silakka54-chevron-cover-B-vim-RH.stl` — lado DIREITO
- Mesma base/plaqueta, **espelhado em X (x = 160,71)**.
- Gravações: **"B"** (Audiowide, cap 5 mm) + **"vim"** (JetBrains Mono Bold, cap 4 mm).
- Texto re-gravado após o espelhamento → legível na posição final (não é espelho de texto).
- Imprimir **direto, sem espelhar**.

### 2.3 `silakka54-baseplate-js-LH.stl` — lado ESQUERDO
- Base: `silakka54-baseplate-screwunderneath.stl`.
- Faixa limpa na borda esquerda (x 21,5–29,5 / y −108,5..−30,5, ≈ 8 × 78 mm) na **face
  inferior** (z = 0,6) — a "carinha" do design anterior foi REMOVIDA a pedido.
- Gravação: **"Foi o JavaScript que me deu"** (JetBrains Mono, cap 2,6 mm auto-ajustada na
  faixa), texto girado 90° (lê-se ao longo do eixo Y), glifos em pé, **sem espelhamento**.
- Profundidade **0,5 mm** (fundo z = 1,10). Imprimir direto.

### 2.4 `silakka54-baseplate-java-RH.stl` — lado DIREITO
- Mesma base, **espelhado em X (x = 97,63)**.
- Gravação: **"Foi o Java que me deu"** (mesmos parâmetros), texto re-gravado legível.
- Imprimir **direto, sem espelhar**.

### Decisões do usuário incorporadas (histórico)
1. Excluir a "carinha" (rosto Tux) da baseplate → baseplates finais só têm a frase.
2. Trocar "FB + Tux" por **"F" (esq.) / "B + vim" (dir.)** nos covers.
3. Frases nas baseplates: *"Foi o JavaScript que me deu"* (esq.) / *"Foi o Java que me deu"*
   (dir.) — texto no **fundo** (visível por baixo), sem inversão (conferido por mapa ASCII
   ray-cast transposto).

### Fontes usadas (licenças)
- **Audiowide** — SIL Open Font License 1.1 (Brian J. Bonislawsky / AOETI)
- **JetBrains Mono** (regular + bold) — OFL 1.1 (JetBrains)

### Verificação técnica (v2)
- 4/4 arquivos **watertight**, sem non-manifold edges (re-carga do STL).
- Profundidades por ray-casting: cover 0,55 mm / baseplate 0,50 mm.
- Espelhamento RH conferido: cover x = 160,71 / baseplate x = 97,63.
- Texto sem inversão: prefixos/sufixos idênticos entre LH/RH no mapa ASCII.
- Hashes de integridade de todos os arquivos: `CHECKSUMS.sha256`.

---

## v2.1 — FINAL ATUALIZADA — covers F | B + "linux" na lateral

Pasta de origem: `ferramentas/out/` (cópias em `01-final/`); v2 antiga → `02-superseded/`

### 2.1.1 `silakka54-chevron-cover-F-linux-LH.stl` — lado ESQUERDO
- Mesma base/plaqueta da v2 ("F", Audiowide cap 5 mm, profundidade 0,55 mm).
- **NOVO: "linux" gravado na lateral esquerda** (texto vertical, JetBrains Mono Bold,
  cap 1,7 mm — auto-ajustada à crista de 2,0 mm; profundidade 0,55 mm, topo medido
  z = 22,35 → fundo z = 21,80).
- Sem "vim" no LH (nunca teve).

### 2.1.2 `silakka54-chevron-cover-B-linux-RH.stl` — lado DIREITO
- Mesma base, espelhado em X (x = 160,71). Plaqueta **"B"** (sem "vim" — decisão do
  usuário) + **"linux"** na lateral direita (mesmos parâmetros do LH, re-gravado legível).

### Correções técnicas (v2.1)
- **Bug de gravação lateral corrigido**: o topo da crista era 22,30–22,35, não 22,2 —
  a gravação fixa 21,65..22,2 deixava as letras enterradas sob uma "tampa" de ~0,1 mm
  (invisíveis). Agora a ferramenta **mede o topo real** no footprint do texto
  (`check_top_flat` + `measure_zmax`) e grava de `ztop−0,55` até `ztop`.
- **Posicionamento**: a crista contínua na faixa lateral tem só 2,0 mm de largura
  (x 147,7..149,7 LH — além disso começa o padrão chevron com vales de até 21,32).
  A ferramenta sonda a crista em duas alturas (21,85 e 22,17) e **reduz o cap
  automaticamente** para o texto caber inteiro na superfície plana (2,6 → 1,7 mm).
- Verificação: mapa ASCII ray-cast a z = ztop−0,15 mostra as letras "linux" completas
  nos dois covers; 4/4 peças watertight (re-carga do STL).

### 2.3/2.4 Baseplates — SEM mudanças
- `silakka54-baseplate-js-LH.stl` / `silakka54-baseplate-java-RH.stl` idênticas à v2.

### Verificação técnica (v2.1)
- Arquivos novos watertight, sem non-manifold edges (re-carga do STL).
- Espelhamento RH conferido: cover x = 160,71.
- Hashes de integridade de todos os arquivos: `CHECKSUMS.sha256`.

---

## v3.0 — VERSÃO ATUAL — Correção de Inversão + Tux + Kit 2-em-1 Carry & Tent

Pasta de origem: `01-final/`

### 3.1 Correção de Espelhamento nas Baseplates (Visão Inferior)
- `silakka54-baseplate-js-LH.stl`: Frase *"Foi o JavaScript que me deu"* gravada na face inferior com rotação 90° e **espelhamento 2D no eixo X**, corrigindo o problema de texto invertido ao virar o teclado por baixo.
- `silakka54-baseplate-java-RH.stl`: Frase *"Foi o Java que me deu"* gravada na face inferior, também com orientação corrigida e 100% legível por baixo.
- Criado script automatizado [`engrave_baseplate.py`](file:///home/fabiominsait/estudos/silakka54-fabio-custom/ferramentas/engrave_baseplate.py) para regeneração precisa e sem erros manuais.

### 3.2 Covers dos Chevrons (FB + Tux + linux)
- `silakka54-chevron-cover-FB-Tux-linux-LH.stl` (LH) e `silakka54-chevron-cover-FB-Tux-linux-RH.stl` (RH):
  - Plaqueta no topo com **"FB"** + **silhueta oficial do Tux (Linux)**.
  - Gravação vertical **"linux"** na crista lateral.
  - Malhas 100% estanques (*watertight*), com volume exato de 13786.4 mm³.

### 3.3 Kit 2-em-1 (Carry Case + Tent)
- Organizado na pasta `01-final/carry-tent-2em1/`:
  - `silakka-case-67mm.stl` e `silakka54-case.stl` (estojos de transporte projetados para comportar o teclado montado junto à plataforma de elevação ergonômica tent/tilt).
  - Componentes do Tent & Tilt Kit: side shells, base supports e tilt wedge.

---

## O que NÃO foi modificado (decisões conscientes)

- **Top frame** (`silakka54-top-frame-screwunderneath.stl`): original, sem gravações.
  Imprimir 2× — uma direta (esquerda) e uma espelhada em X (direita).

---

## Regenerar / modificar depois

Os STLs finais foram gerados por script (`engrave_baseplate.py` e `engrave_cover.py`). Para alterar textos,
fontes, tamanhos ou posições: executar os scripts em `ferramentas/`. Regra prática: **LH nunca espelha; RH já vem espelhado com texto
re-gravado** — nunca aplicar espelhamento duplo.

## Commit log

2026-08-10 feat: pacote de impressao Silakka54 personalizado (F/B + linux lateral) + ferramenta engrave_cover.py
    [50pct-mcu-cover.stl, 75pct-mcu-cover.stl, full-mcu-cover-chevrons.stl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]
2026-08-10 feat(site): GitHub Pages com visualizador 3D (three.js CDN) + guia de ergonomia
2026-08-10 feat(site): +12 peças no viewer (carry case + tent/tilt kit), galeria de fotos, previews gerados, título 'por Fabio'; chore: rename repo silakka54-fabio-custom
2026-08-10 docs(ferramentas): LEIA-ME.md com comandos de reuso (engrave_cover.py + make_previews.py)
2026-08-10 docs(VIAL): web app 0.7.5 salva .vil + unlock combo Esc+1 (pesquisa librarian)
2026-08-27 feat(v3.0): correcao de orientacao de texto nas baseplates, covers FB+Tux+linux, kit 2-em-1 carry&tent e super-zoom no site
    [silakka-case-67mm.stl, silakka54-baseplate-java-RH.stl, silakka54-baseplate-js-LH.stl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]
2026-08-28 feat(ecosystem): integracao do combo 3-em-1 (Slim Case, Tent & Tilt 10-15°, Carry Case 67mm para Keycaps XDA) e super-zoom no site
    [silakka54_inner_frame.stl, silakka54_mcu_left.stl, silakka54_mcu_right.stl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]
2026-08-28 feat(custom-slim): tampas MCU personalizadas F+linux e B+linux para a Slim Screwless Case
    [silakka54-slim-mcu-cover-B-linux-RH.stl, silakka54-slim-mcu-cover-F-linux-LH.stl, silakka54-slim-mcu-cover-FB-Tux-linux-LH.stl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]
2026-08-28 feat(palm-rest): Apoio de Palma com Tenting (12.4°) ergonomico e resistente para o Silakka54 (LH e RH)
    [silakka54-tented-palm-rest-LH.stl, silakka54-tented-palm-rest-RH.stl]
2026-08-28 feat(slim-case-phrases): gravacao das frases no fundo solido da Slim Screwless Case (LH e RH)
    [silakka54-slim-case-java-RH.stl, silakka54-slim-case-js-LH.stl]
2026-08-28 feat(typography): frases em JetBrains Mono (IntelliJ) com margens confortaveis e sem encostar na borda
    [silakka54-baseplate-java-RH.stl, silakka54-baseplate-js-LH.stl, silakka54-slim-case-java-RH.stl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]
2026-08-28 feat(carry-case): gravacao personalizada de FábioHMB + silakka54 (cursiva) + Tux Linux no Carry Case 67mm
    [silakka-case-67mm.stl]
2026-08-28 fix(mcu-cover & 3d-viewer): afasta texto 'linux' do furo e corrige race condition de sobreposicao de malhas no visualizador 3D
    [silakka54-slim-mcu-cover-B-linux-RH.stl, silakka54-slim-mcu-cover-F-linux-LH.stl]
2026-08-28 feat(slim-case): gravacao das frases na parede LATERAL externa da Slim Case (LH e RH)
    [silakka54-slim-case-java-RH.stl, silakka54-slim-case-js-LH.stl]
2026-08-28 feat(carry-case): grava FHMB + silakka54 (cursiva) + Tux na parede principal externa visivel do Carry Case
    [silakka-case-67mm.stl]
2026-08-28 feat(palm-rest): rampa 100% lisa, plana e uniforme sem depressao/bolinha com inclinacao pura de 12.4°
    [silakka54-tented-palm-rest-LH.stl, silakka54-tented-palm-rest-RH.stl]
2026-08-28 feat(slim-case): gravacao 100% na parede LATERAL externa (LH e RH) sem nada no fundo e com cache-busting
    [silakka54-slim-case-java-RH.stl, silakka54-slim-case-js-LH.stl]
2026-08-28 feat(carry-case): grava o emblema completo (FHMB + silakka54 cursiva + Tux) na parede frontal do Carry Case 67mm
    [silakka-case-67mm.stl]
2026-08-28 fix(typography): desespelha orientacao do texto nas paredes laterais (LH e RH) e na Carry Case
    [silakka54-slim-case-java-RH.stl, silakka54-slim-case-js-LH.stl]
2026-08-28 fix(carry-case): desespelha horizontalmente o emblema (FHMB + silakka54 + Tux) para leitura correta
    [silakka-case-67mm.stl]
2026-08-28 fix(tux-vector): substitui silhueta por vetor oficial do Tux Linux com pezinhos anatômicos limpos e suaves
    [silakka-case-67mm.stl]
2026-08-28 feat(tux): modela o Tux classico (Larry Ewing) com patinhas anatomicas arredondadas e definidas
    [silakka-case-67mm.stl]
2026-08-28 feat(carry-case): remove icone do Tux e centraliza FHMB + silakka54 na parede externa do Carry Case
    [silakka-case-67mm.stl]
2026-08-28 feat(download): disponibiliza pacote ZIP completo com todos os modelos (teclado, apoios tented/planos, tenting kit e carry case)
    [silakka54-flat-palm-rest-LH.stl, silakka54-flat-palm-rest-RH.stl]
2026-08-28 feat(carry-case): grava FHMB + silakka54 nas DUAS paredes externas do Carry Case (visivel em qualquer angulo de camera)
    [silakka-case-67mm.stl]
2026-08-28 fix(docs): atualiza texto do combo 3-em-1 para Carry Case (FHMB + silakka54)
2026-08-28 feat(carry-case): restaura Carry Case 67mm 100% liso e limpo sem nenhuma gravacao
    [silakka-case-67mm.stl]
2026-08-28 feat(carry-case): grava com destaque FHMB + silakka54 (cursiva) nas duas paredes externas do Carry Case
    [silakka-case-67mm.stl]
2026-08-28 feat(web): copia 01-final para dentro de docs/ e configura carregamento 100% local sem atraso de CDN
    [silakka-case-67mm.stl, silakka54-baseplate-java-RH.stl, silakka54-baseplate-js-LH.stl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]
2026-08-28 feat(carry-case): grava FHMB + silakka54 APENAS na parede reta/plana com profundidade suave de 0.48mm e remove do lado com curvas
    [silakka-case-67mm.stl]
2026-09-05 feat(cheatmap): full interactive typing arena with physical switch tracking, switch sounds, WPM, and practice modes
